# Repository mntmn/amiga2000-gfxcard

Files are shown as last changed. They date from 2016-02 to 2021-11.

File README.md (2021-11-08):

# MNT VA2000, an Amiga 2000 Graphics Card (Zorro II/III)

_Update January 16th, 2017:_ The MNT VA2000 is now a finished product (credits go to Scarab Hardware for making this happen) that you can buy. I shipped the first batch of 100 cards on christmas 2016 and the second batch is now being made. 

You can still grab one: http://mntshop.bigcartel.com/product/mnt-va2000-amiga-graphics-card-zorro-ii-iii-batch-2-preorder

The latest firmware update and drivers are always available here: http://mntmn.com/va2000/

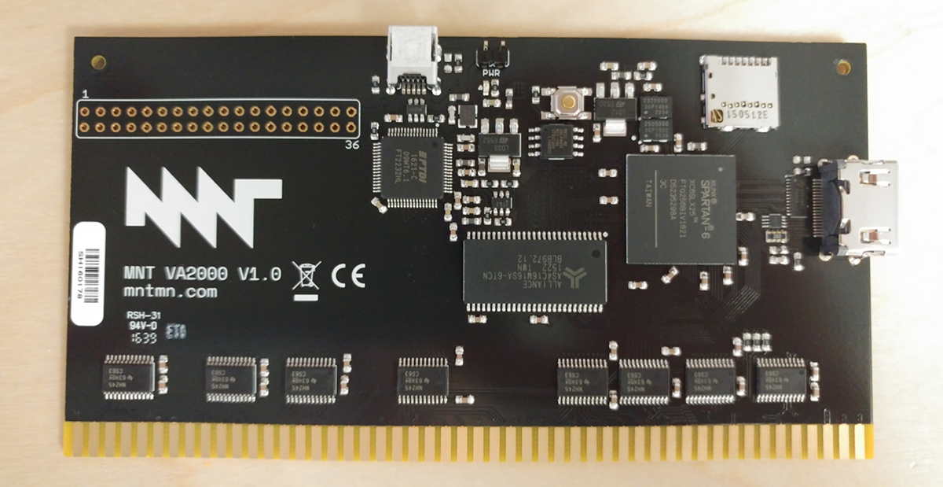
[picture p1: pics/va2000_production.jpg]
MNT VA2000 Finished Product


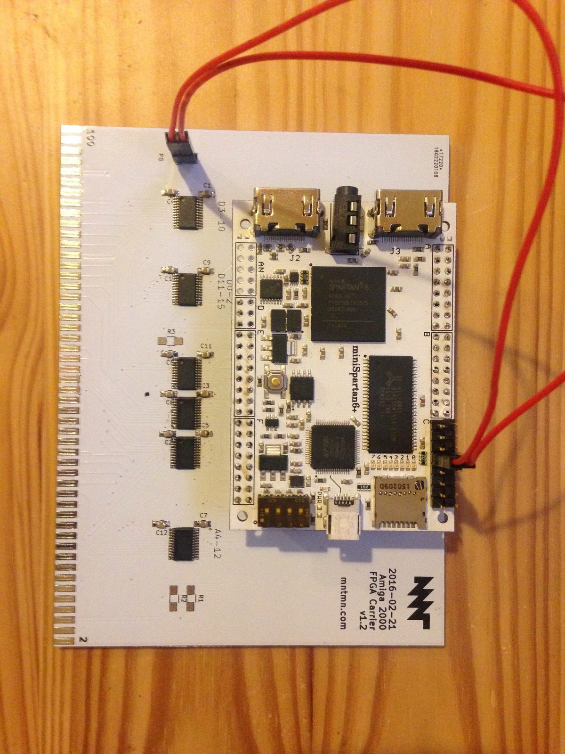
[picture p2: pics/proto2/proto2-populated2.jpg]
MNT VA2000 Protoype 2 Populated


This repository contains my Kicad schematics and Xilinx ISE/Verilog files for my graphics card project. This is a work in progress, started in October 2015. The first 4 prototypes were assembled in Jan/Feb 2016 and had noise problems, so I started a redesign on Feb 13, 2016.

On Mar 27th, 2016, the redesign worked and I could load a 16 bit 565BGR coded raw image from floppy into the graphics card that displayed a 1280x720p resolution (75mhz pixelclock).

In April 2016, I managed to get Workbench running via a reverse engineered Picasso96 driver.

The working Xilinx project for the new target platform (Scarab miniSpartan 6+) is now in the z2-minispartan folder. The main source file is: https://github.com/mntmn/amiga2000-gfxcard/blob/master/z2-minispartan/z2.v

Contains a modified SDRAM controller (Verilog) and a DVI encoder (VHDL) by Mike Field. See credits and license at the end.

# How I decided to make a graphics card for my Amiga 2000

_TL;DR: I spent my free time over the course of 5 months to make two open source graphics card prototypes for the Amiga 2000. I will make a third, release version; details at the end._

Somewhere in the middle of 2015 I revived my old A500 and acquired again an A1200. Using the A1200, I learned C++ and the basics of web programming in the late 90s. I also used to play many fantastic Amiga games back in the day, made my first music in ProTracker and my first digital graphics in Deluxe Paint. Re-experiencing the old system that was once so ahead of its time again made me curious about Commodore's history – and especially about the later, big and ambitious Amiga models (A3000, A4000…). This coincided with Amiga's 30th anniversary. A lot of new interviews with the original team(s) popped up, including Dave Haynie, who was a main designer of the A2000 and the Zorro III Bus.

I checked eBay for the "big" Amigas I never had, expecting them to be cheap, but found out that these boxes had turned into valuable collector's items. At the same time, A2000s were (and still are) affordable, so I chose to get one and put a 68040 and a SCSI card in it. But the system couldn't realize it's full potential; in the 90s you could already get, for example, a "Picasso" graphics card that could do VGA (and higher) resolutions at 16 or 24bit color depth. Nowadays, these totally outdated cards are rare and sold for ridiculous prices. My A2000 was stuck with 640x256 PAL resolution, 64 colors (ignoring HAM) or headache-inducing interlaced modes. 

Because of my work with microcontrollers, writing an OS for Raspberry Pi (http://interim.mntmn.com/) and my interest in low-level computer architectures in general, I decided in October 2015 in a feat of madness: "I'll just make my own graphics card. How hard can it be?"

It turned out to be a very, very challenging project, but luckily I got much further than expected. On the way, I had to learn how to design a PCB and get it manufactured, how to work with SMD parts, how to program in Verilog and synthesize code for an FPGA, how SDRAM and DVI/HDMI work (or how to get them to do at least something). I also had to find out how to write a driver for the sadly closed/undocumented Picasso96 "retargetable" graphics stack for AmigaOS 3.

The Amiga is probably the last 32-bit personal computer that is fully understood, documented and hackable. Both its hardware and software contain many gems of engineering and design. I hope that one day, we can have a simple but powerful modern computer that is at the same time as hackable and friendly as the Amiga was.

## The "engine": FPGA and SDRAM

As a platform for my first attempt (ultimately a failure) I chose the Papilio Pro development board, which has a Xilinx Spartan 6 FPGA and a few megabytes of SDRAM connected to it. It also has two pin headers that break out some of the general purpose input/output pins of the Spartan. I thought, OK – I could use the RAM to store the image (a framebuffer), and run a loop that goes through all the columns and rows of the picture in the correct speed and just output the bytes from the RAM to R,G and B output lines. I did this before with little Atmel microcontrollers – "bit-banging" a VGA image directly from the CPU – so I knew it was possible. I just didn't know that SDRAM (synchronous dynamic RAM) was a lot more complex to use than the integrated SRAM (static RAM) of common microcontrollers. To access data in a dynamic ram, you have to open banks, rows, precharge, refresh, and take care of startup and access delays:

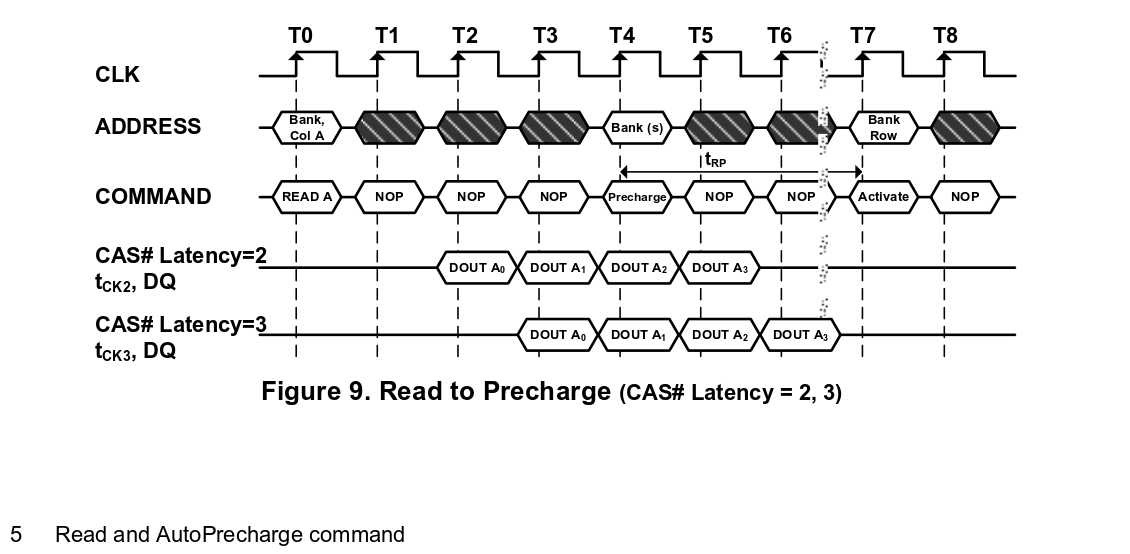
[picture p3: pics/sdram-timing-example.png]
SDRAM Timing Example from Alliance Memory Datasheet


Source: http://www.alliancememory.com/pdf/dram/256m-as4c16m16s.pdf

Mike Field's open source SDRAM controller written in VHDL and Verilog helped me get the RAM working. I connected an Arduino to the Papilio and used it to send a few address bits and an "on/off" bit to toggle pixels in the framebuffer black or white. This contraption was able to draw basic fonts on my VGA display, and they were successfully kept in the SDRAM. 

The next step was connecting the FPGA+display part to the Amiga 2000.

## Zorro II: Reads and Writes

The original Amiga Hardware Manuals helped me understand the Zorro II bus. It is basically an extension (arbitrated by a bus controller chip) of the pins of the Motorola 68000 CPU. The 68k is extensively studied and documented. I understood that I needed a mechanism that would allow the 68k CPU to write data (pixels) to the graphics card's RAM and another for reading back parts of the screen (for scrolling and moving around things).

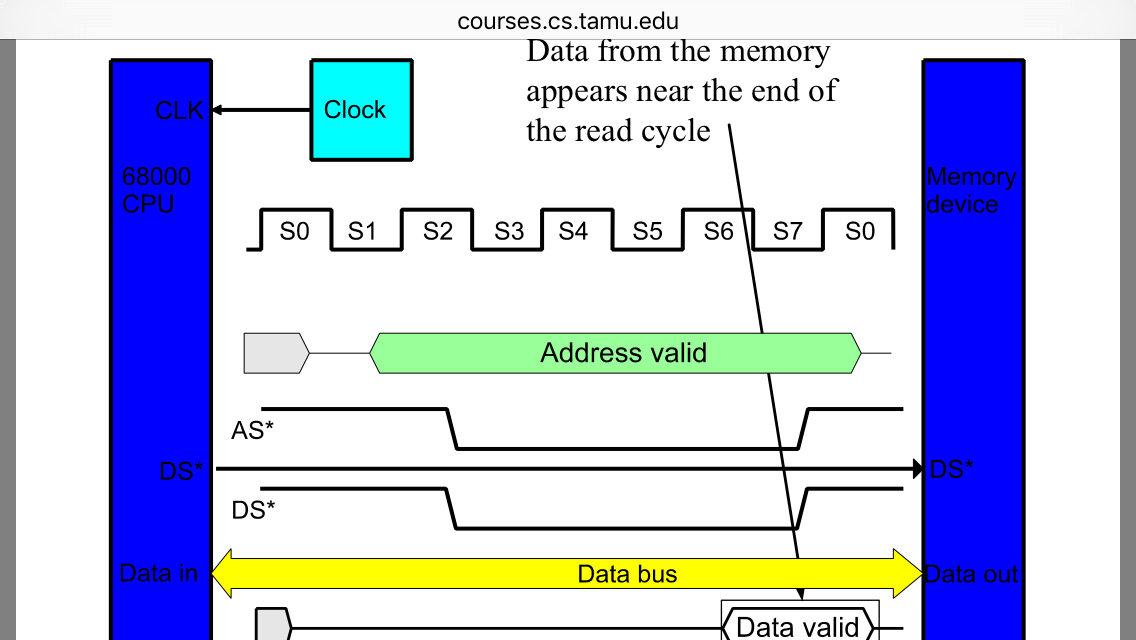
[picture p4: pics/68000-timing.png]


So I fired up the open source circuit design tool KiCad and started some schematics. The first task was to define the Zorro port as a component with a whopping 100 pins. Of course I made a lot of little mistakes at first and I had no idea why one would need so many different signals. It turned out that I only needed a subset of the pins to get my job done:

1. Address Bus (A1-A23)
2. Data Bus (D0-D15)
3. Upper and Lower "Data Strobes" (UDS / LDS)
4. READ, /AS, DOE, signals which the Amiga uses to communicate if it wants to read or write, if it presents a valid address and if it expects a device to send data.
5. Power (5V, GND)
6. Autoconf (/CFGIN, /CFGOUT)

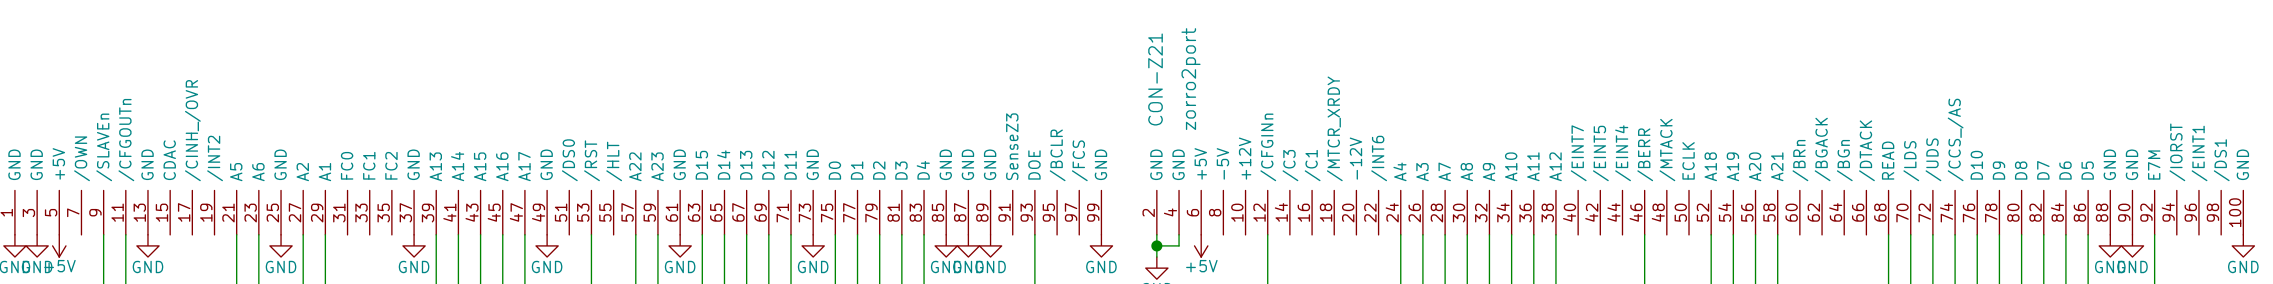
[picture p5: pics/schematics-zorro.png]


Source: http://courses.cs.tamu.edu/cpsc462/walker/Slides/68K_Timing_Diagrams.pdf

I figured that I needed to connect most of these signals to the FPGA and then write another loop in Verilog that would interpret the Amiga's bus commands and act on them (store the data given on the bus in the RAM or return stuff from the RAM). 

On the other side of the FPGA, I decided to place an Analog Devices ADV7125 digital to analog converter (DAC) chip that would generate the analog R, G and B channels for the VGA port from the bits coming from the framebuffer.

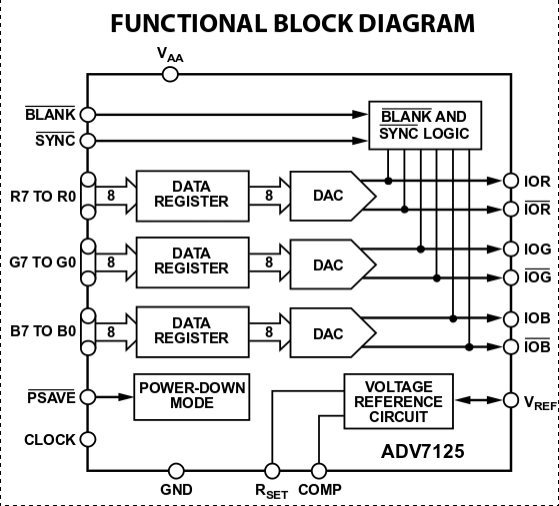
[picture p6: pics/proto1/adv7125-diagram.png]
Analog Devices ADV7125


Source: http://www.analog.com/media/en/technical-documentation/data-sheets/ADV7125.pdf

The next hurdle appeared: The Spartan communicate with modern 3.3V logic levels, but the Amiga used legacy 5V signals. So I needed to put voltage translators (also called level shifters) between the Zorro and the FPGA pins. I decided to split the signals into bundles of 8 and use six 8-bit "auto-direction-sensing" TXS0108 chips.

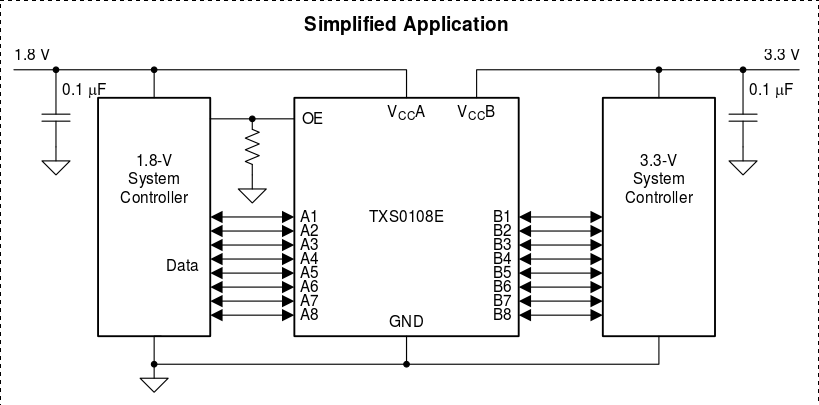
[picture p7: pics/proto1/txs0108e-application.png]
Texas Instruments TXS0108


Source: http://www.ti.com/lit/ds/symlink/txs0108e.pdf

## Mistake: Trying to be too smart

I then realized that the Papilio, the FPGA board I had, didn't have enough I/O pins to connect to the 48 Zorro signals and the 16+2 pins required for the VGA DAC output. Actually, it had a lot less pins. So I made a huge mistake and decided to use two 16-bit port switching chips and "select" on the fly a "window" of the Zorro pins that would be relevant at each state of my bus communication loop; I thought I didn't need to access the data pins at the same time as the address pins. And because the FPGA runs at a much higher frequency than the Zorro bus, I could first read one part of the address, switch one of the switches via a control pin and then quickly read the other part to get the whole address.

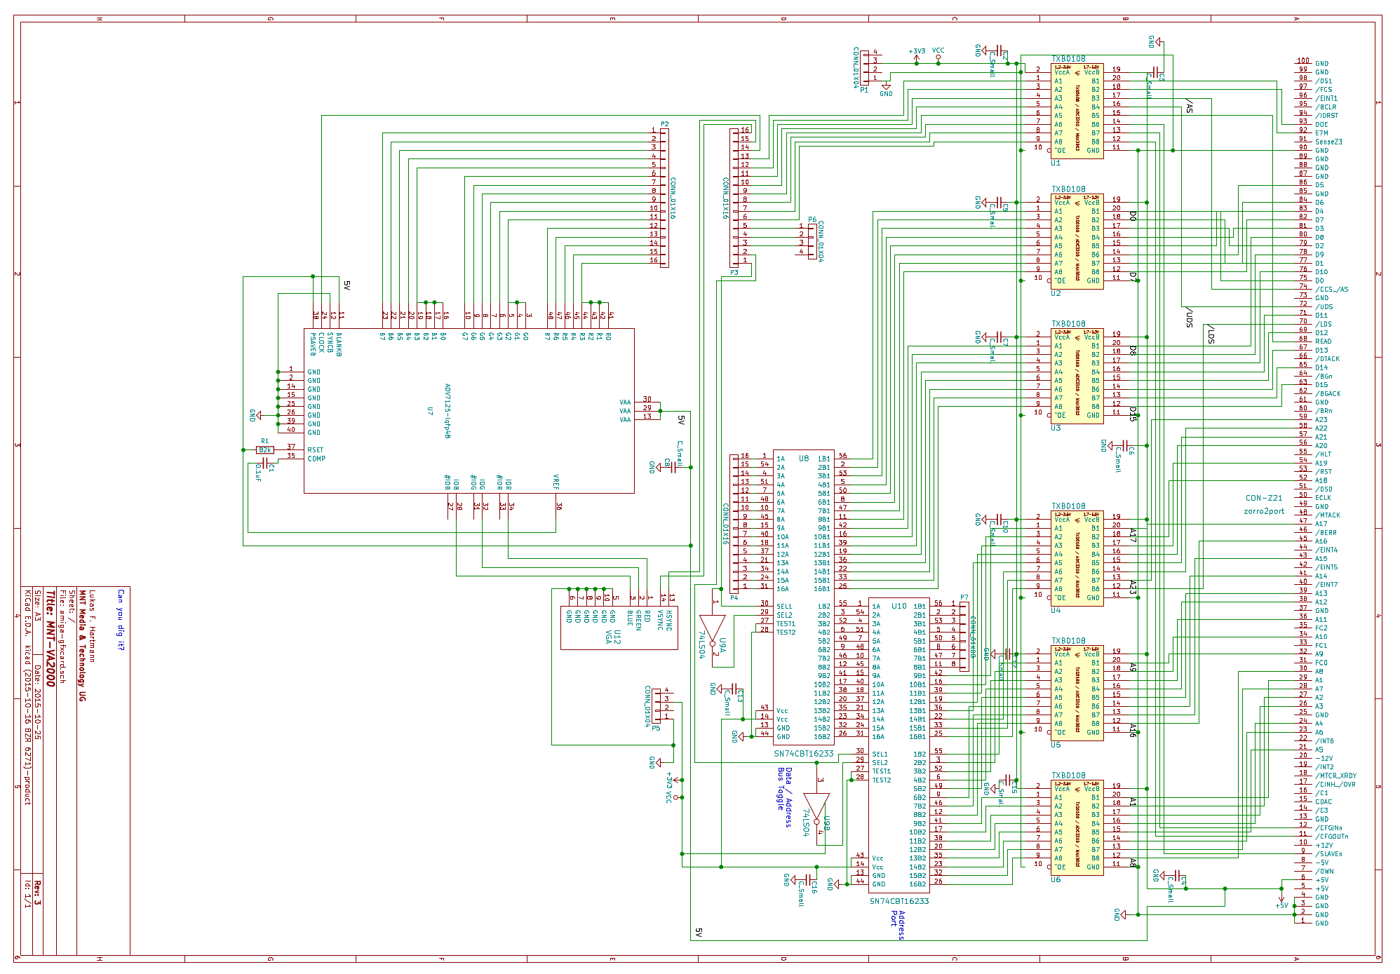
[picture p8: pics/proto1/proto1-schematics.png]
Failed Prototype 1 Schematics
 

After drawing up a few versions of the schematics and collecting the fitting footprints for the components from various GitHub repositories, I imported them into KiCad's PCB design tool and started drawing the actual circuit board. I had no experience doing this, so I worked through tutorials or just looked at how other people were solving their board design problems. Finally, I uploaded the exported "Gerber" files to DirtyPCBs.com, ordered, waited 8 weeks and nothing happened. I made the mistake of choosing the AirMail option, which has no tracking, and the package was lost. After getting no support from DirtyPCB, I chose to try again, this time selecting the DHL option with tracking and finally got my first ever printed circuit boards in the mail around 10 days later! By now, it was the middle of January 2016.

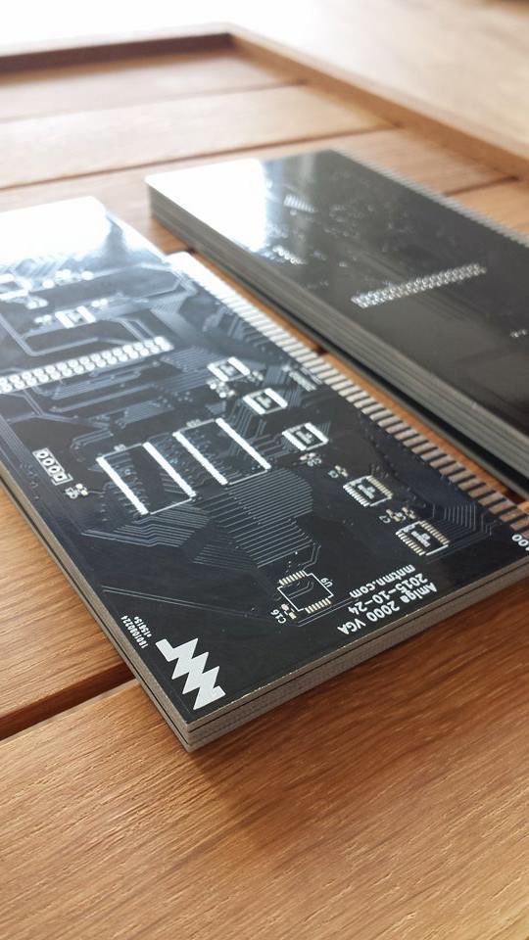
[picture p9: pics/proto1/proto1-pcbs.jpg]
Prototype 1 PCBs


In parallel, I ordered the required chips and parts from Mouser; luckily I had gotten most of the footprints right, except for one logic gate IC that turned out to be a mistake anyway. I got to work and tried to solder my first SMD ICs using my trusted ERSA iron. 

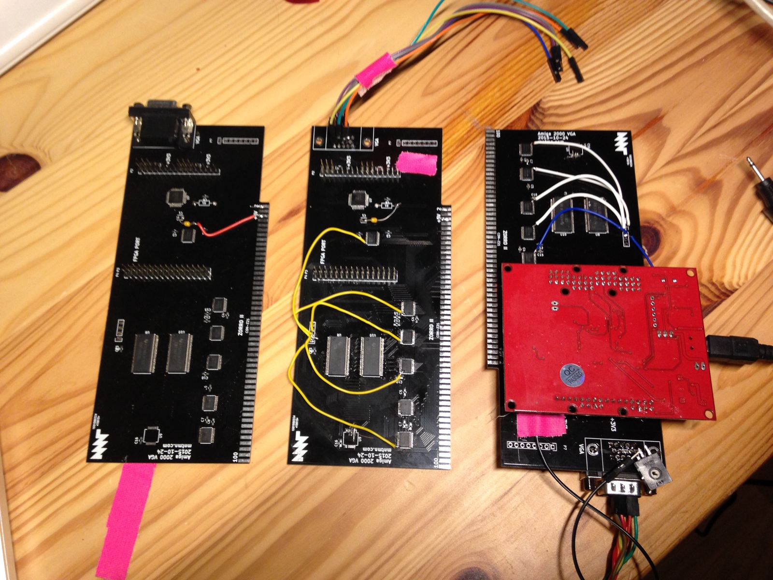
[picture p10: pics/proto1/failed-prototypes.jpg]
Failed Prototype 1 Board
 

It turned out I had made a number of critical mistakes in designing the boards: all of the voltage translators' OE pins were tied to GND when they should have had 3.3V, so they required manual bending and patching of the OE leg (yellow cables in the picture). I accidentally switched 3.3V and GND pins on the FPGA carrier headers, so I needed to reroute them with wires on the back. Because I misinterpreted the Multiplexer IC's datasheet, I also planned for a negating logic IC on their SEL pins which was totaly wrong. In the end I had to solder bridges instead of placing the 74LS04. 

After fighting through all of these issues and burning through a few boards, I finally got some results. As a first debugging step, I wrote a poor man's logic analyzer in Verilog that would record 640 cycles of all the Zorro Bus signals to FPGA registers (BRAM) and dump them as colorful lines on the VGA screen. This turned out to be a helpful instrument. I wrote a very simple program in 68k assembler for the Amiga that would read – in an endless loop – a word from address $e80000 and write it to $dff180 (a background color register). I made a boot floppy that would run the program, put my card in the A2000, flashed the code and turned everything on.

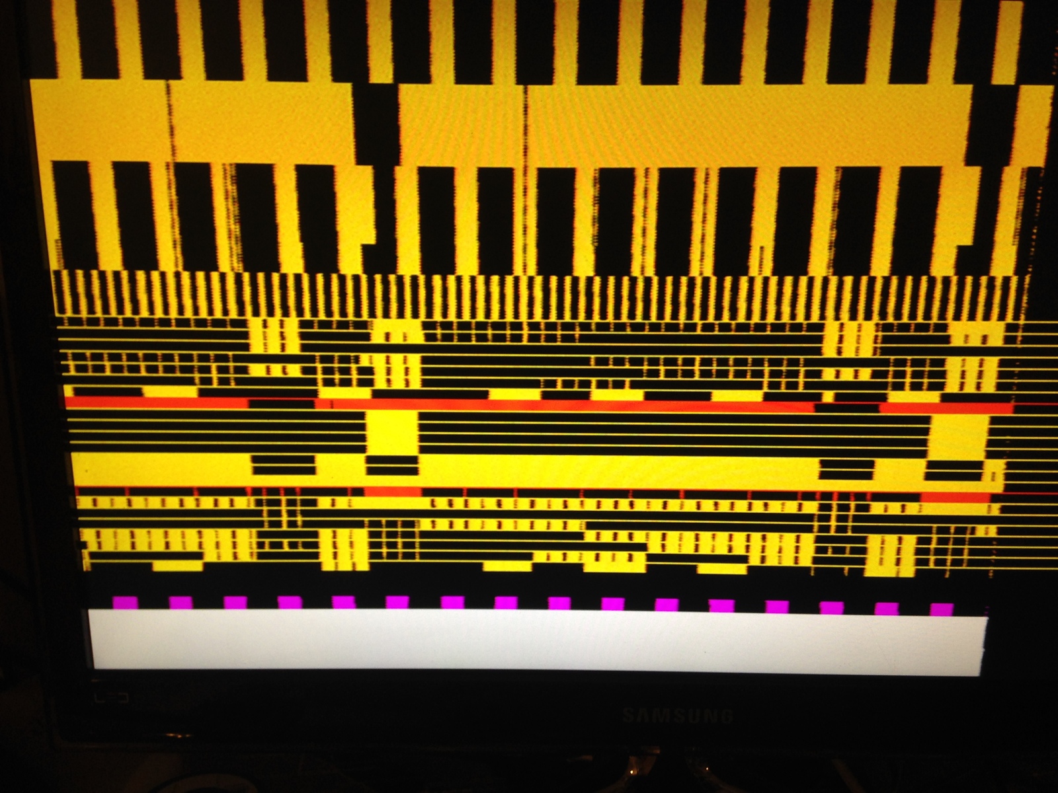
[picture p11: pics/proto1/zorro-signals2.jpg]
Prototype 1 Zorro Bus Analyzer 1
 

The first 5 longer, stretched rows in this picture are the signals DOE, READ, /UDS, /AS and E7M (Amiga 7Mhz Clock) sampled at 100 Mhz/Column, so the whole picture displays a time sample of 6400ns (nanoseconds) or 6.4&mu;s (microseconds).

The following lines on the grid represent the Address bits A23-A1 in descending order. A0 does not exist; the 68000 selects an upper, lower or both bytes (word access) using /UDS and /LDS instead.

The address signals have regular little chops in them; this is a nasty side effect of switching the multiplexers. You can also see that address bit A9 is constantly turned on, probably due to a soldering error. At least it's possible to see the 68000's read and subsequent write accesses (the only hole in the READ row, second from the top). Ignoring the broken pins A9 and A17, the READ occurs as expected on address binary 111010000000000000000000 and the WRITE on 0b110111111111000110000000. Due to the constant noise and other random failures, I couldn't reliably get the Amiga to read from my card, but it worked at least sometimes, giving me hope.

After a few nights of trying to fix this very unstable system, I gave up and went back to the drawing board.

## Redesign and Breakthrough

My new strategy was:
1. Make the board much simpler, focus on voltage translation and find a FPGA board with enough IOs
2. Get a decent (de-)soldering station and learn a better SMD soldering technique

I shopped around the web for FPGA boards that combine SDRAM with lots of IO breakouts and found Scarab Hardware's miniSpartan6+, which has a nice small formfactor and includes two HDMI ports, a mini SD card reader and even an audio jack. 

I redrew the schematics to include no more switches, different level shifters with explicit direction inputs (NXP 74LVC8T245), plenty of bypass capacitors and dropped the analog VGA circuit. 

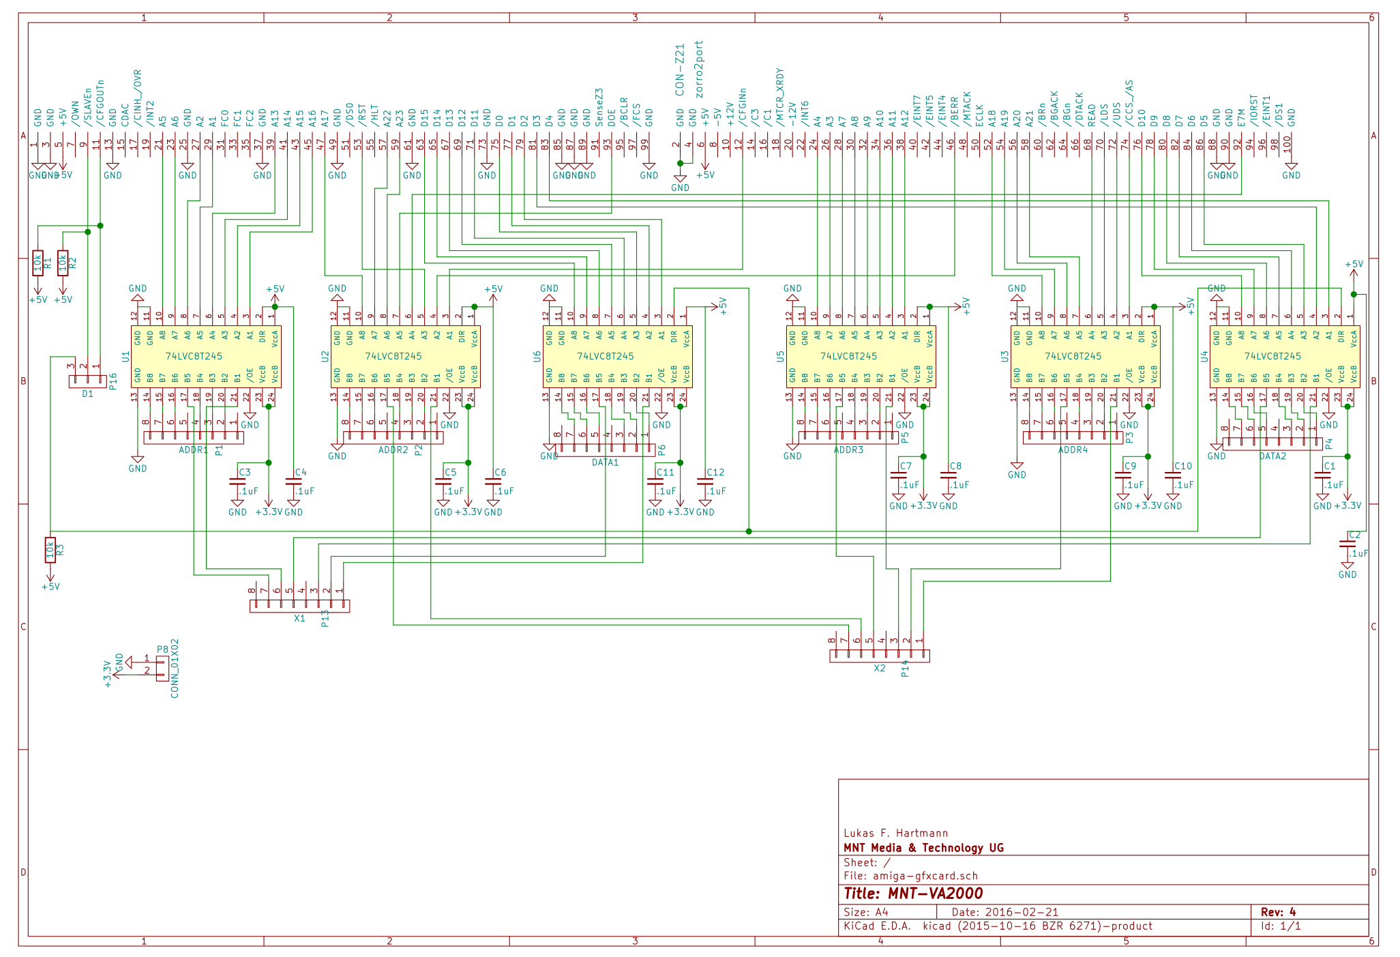
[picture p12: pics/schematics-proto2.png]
Prototype 2 Schematics

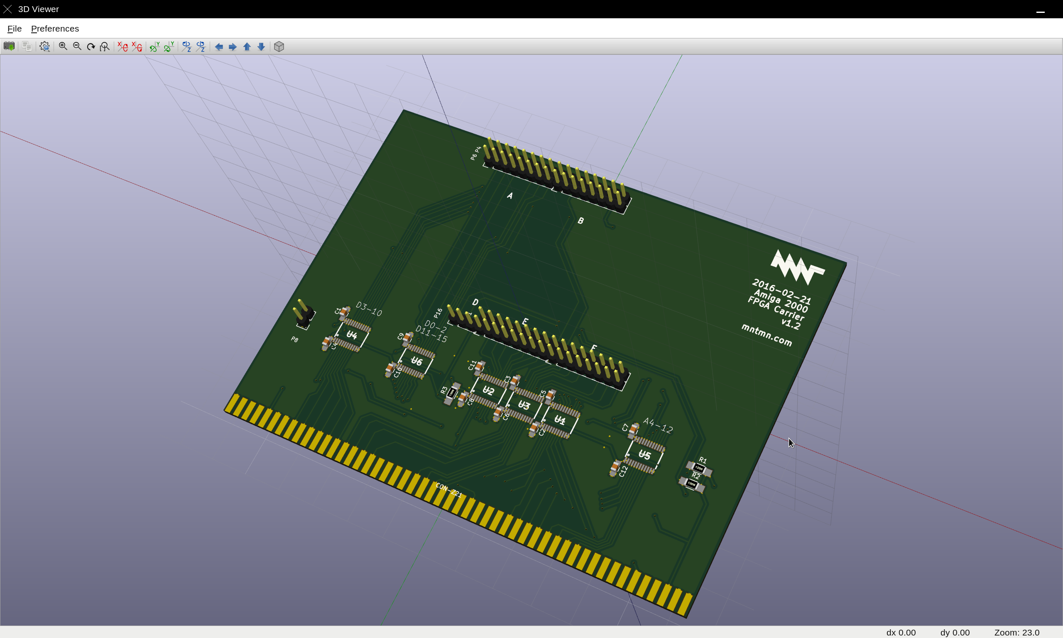
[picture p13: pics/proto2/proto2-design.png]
Prototype 2 Design


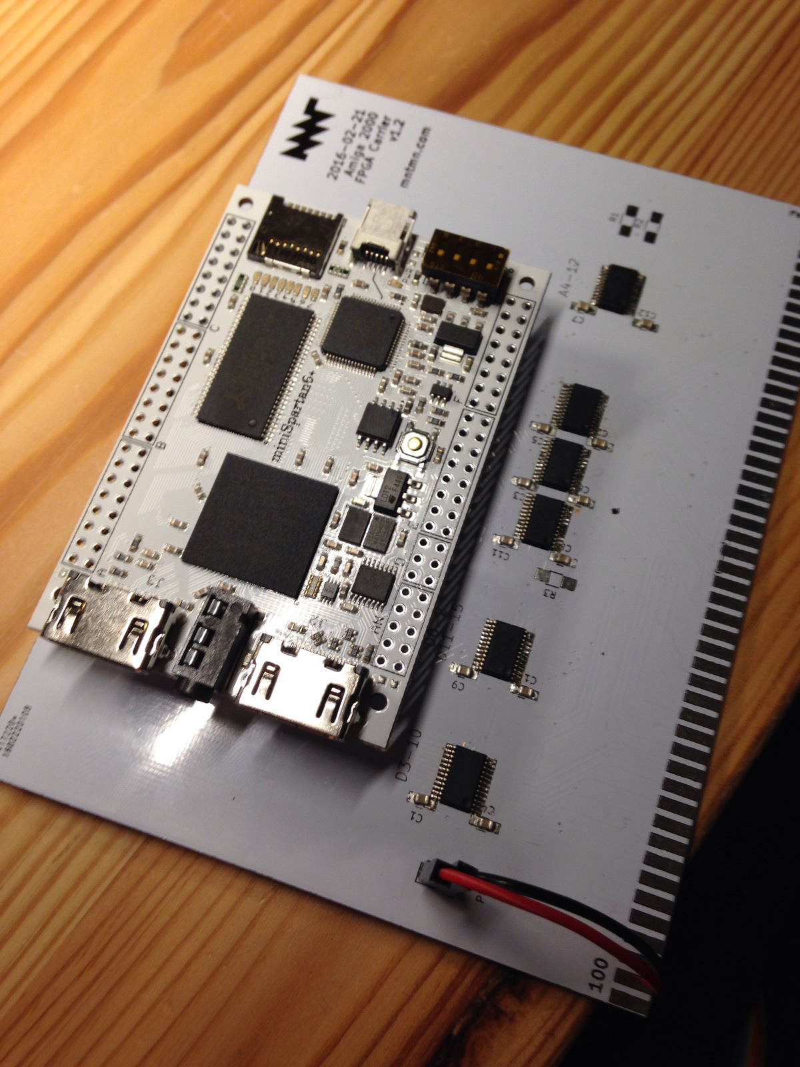
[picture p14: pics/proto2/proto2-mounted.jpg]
Prototype 2 with miniSpartan mounted


To solve point 2, I ordered a Yihua 853D rework station on Aliexpress and experimented with hot air solder paste soldering (not a success for me, the results were quite messy). I then watched Sparky's super helpful SMD soldering techniques again: https://www.youtube.com/watch?v=z7Tu8NXu5UA

To my surprise, using the "dragging" technique with plenty of flux and a chisel tip (Sparky recommends a "gullwing" tip) at around 270 Celsius yielded the cleanest results I had so far.

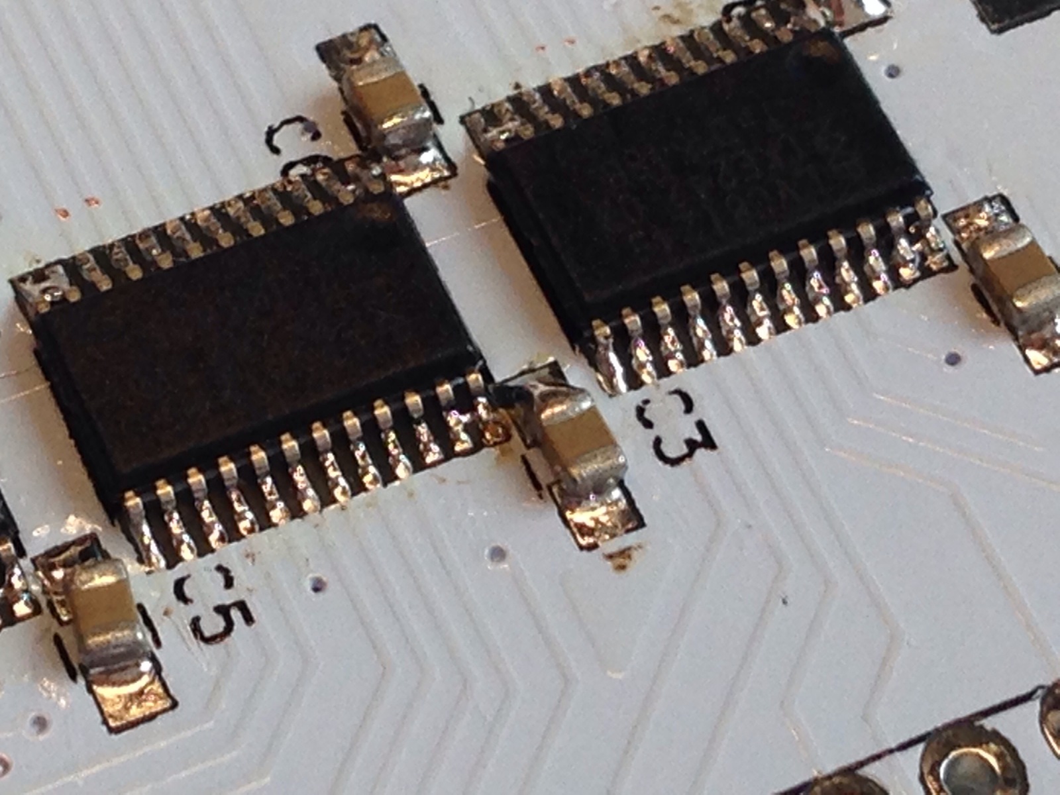
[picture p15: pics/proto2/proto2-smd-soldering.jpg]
Drag Soldered Voltage Translators

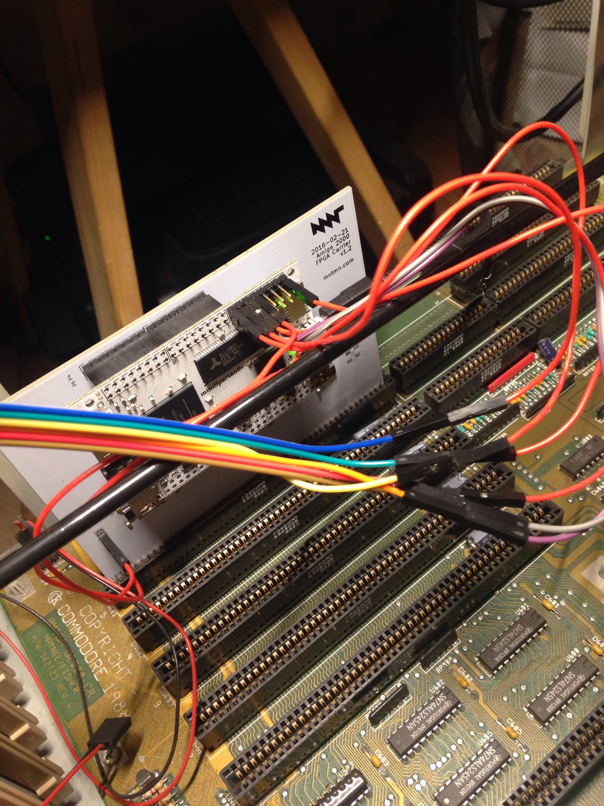
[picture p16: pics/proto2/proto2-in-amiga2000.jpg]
Prototype 2 inserted into Amiga 2000


Version 2 rewarded me with super clean signals. I used 5 digital outputs of the FPGA and connected them to a VGA monitor for testing, and I could reliably "lock" my Verilog state machine to the Zorro READ cycles. 

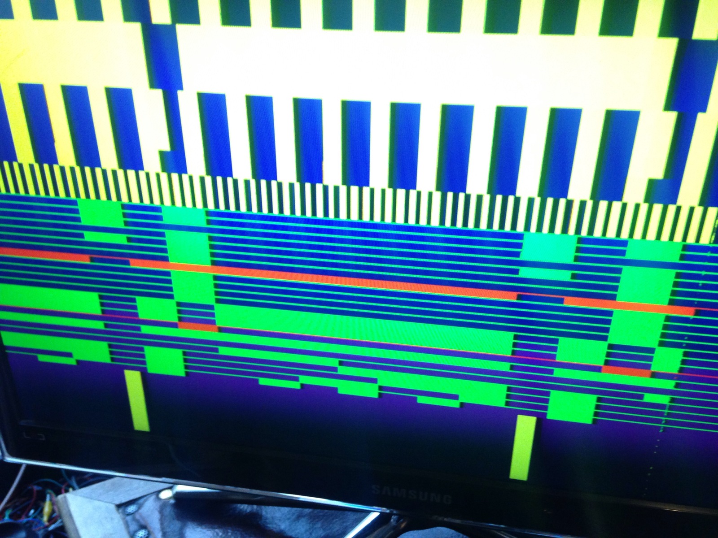
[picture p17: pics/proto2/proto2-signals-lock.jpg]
Prototype 2 Clean Signals


I proceeded to write a little 68k assembler program that reads the Amiga's mouse X and Y registers and translates them into an address for the graphics card to write a pixel to. And voila, I had a primitive painting program:

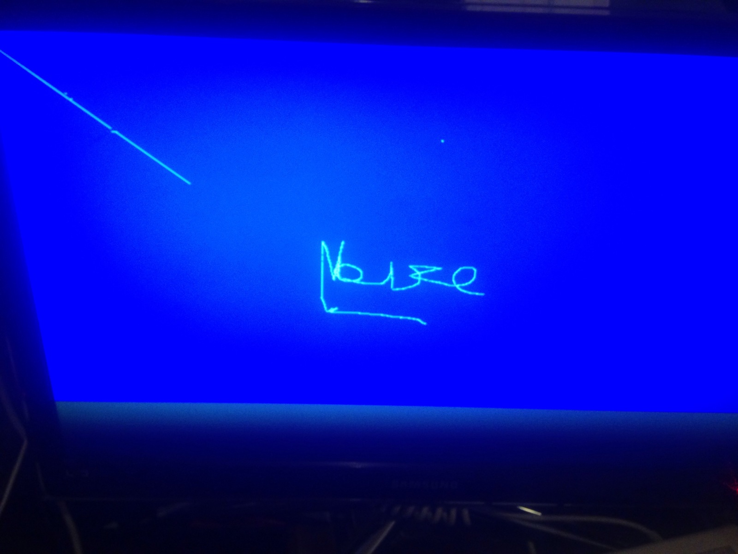
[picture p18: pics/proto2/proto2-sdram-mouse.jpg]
Prototype 2 Assembler Mouse Test


The main problems I had to solve now revolved around tweaking the state machine so that it would arbitrate the single RAM port between fetching pixels for display on the screen – something that is almost constantly happening, only not during blanking periods – and Amiga reads and writes to and from the graphics RAM. I still haven't completely solved this challenge, but I've come far enough for the system to be somewhat usable. The current algorithm works like this:

### Fetching

Shortly before the beginning of each displayed row, start the pixel _fetching_ process. In this state, a line buffer is normally filled with pixels for that line from SDRAM as fast as possible (133 MHz clock).

### Displaying

The VGA/DVI output process reads the pixels to be displayed from this line buffer at the pixel clock frequency (60~75 MHz for a 1280x720 output). This means that the fetching process always needs to be at least as quick or quicker than the displaying process, or there will be glitches (doubling of the last line).

### Host Writes

When the host CPU wants to write to graphics RAM, we don't let it write directly to the SDRAM (because we're probably currently accessing it for fetches). Instead, we save the host's write address and data to a _write queue_. The queue is drained (processed) whenever the line fetching is done for a row and in blanking periods.

I tested the stability of writes by putting the "mon" tool (http://aminet.net/package/dev/moni/mon165) on a floppy together with a raw 16 bit image (rgb565) of a mountain. I loaded this directly into graphics card memory starting at $600000, displaying the first picture ever on my board:

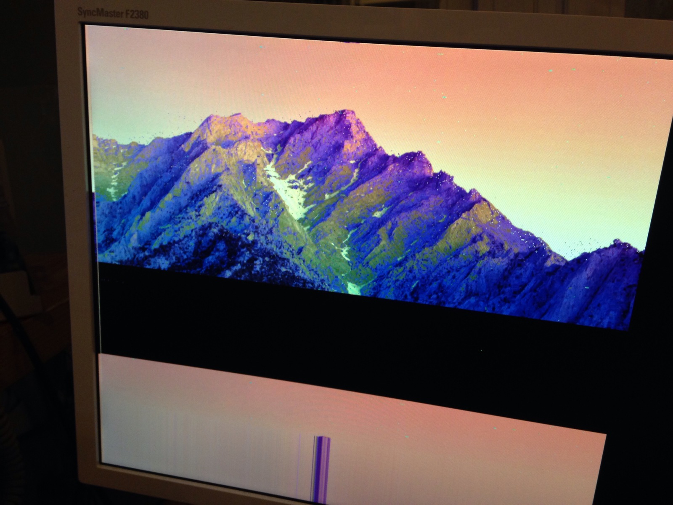
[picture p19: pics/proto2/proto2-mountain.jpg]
Prototype 2 Picture Load Test


### Host Reads

I found host read timing to be significantly harder to get right, and it's still not perfect. Host reads can't be put in a queue and have to be processed immediately. This interrupts the fetching process; if the host needs to read from a totally different memory location then the display engine is fetching, the SDRAM has to close, refresh and reopen rows, which is a time consuming process. So far, reads from the host cause temporary distortions (glitches) in the display output. I plan to mitigate these problems using either burst mode reads and fast switching and/or inserting CPU wait states via the XRDY signal.

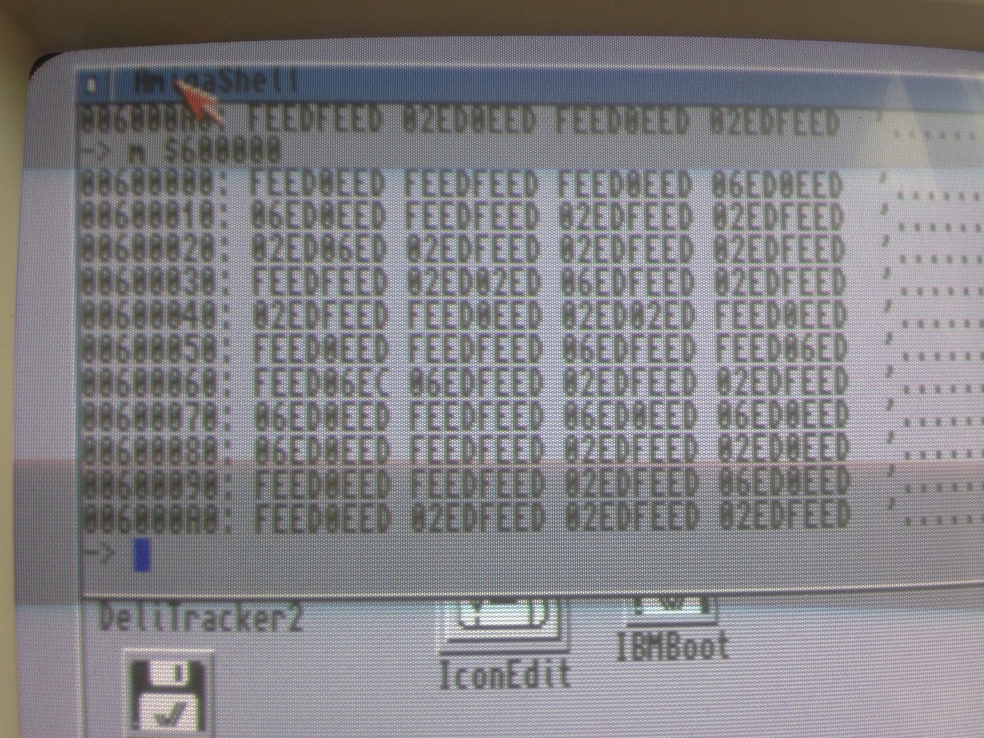
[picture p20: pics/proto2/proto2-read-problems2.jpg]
Prototype 2 READ Problems

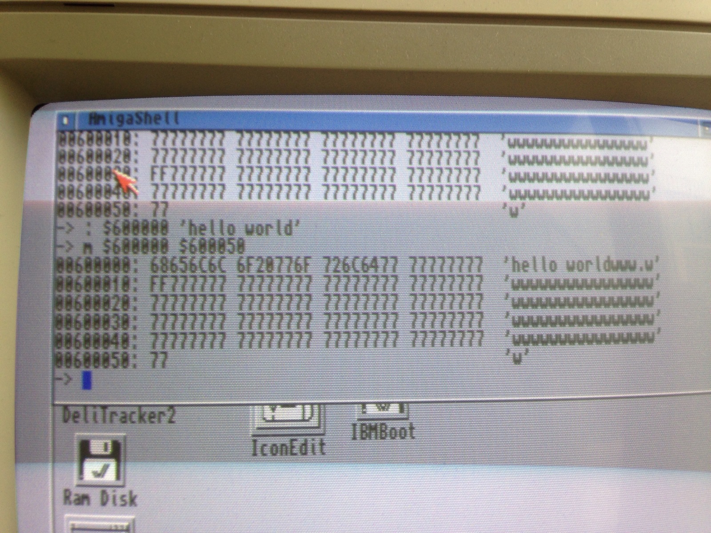
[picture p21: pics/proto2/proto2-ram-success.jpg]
Prototype 2 better READs


## Picasso96: Writing a Driver for a Closed System

Picasso96 was one of two competing systems (the other being CyberGraphX) integrating graphics cards into the Amiga "Monitor" Device system. P96 also ships an "emulation.library" that patches all system windowing and drawing functions and redirect the legacy bit-planar based output to the new "chunky" pixel formats. After the death of Commodore and the Amiga market, Village Tronic, the authors of P96, disappeared. It's unclear where the sources and internal documentation ended up, and the original developers didn't respond to my emails about it.

I looked at the publically available P96 binaries and documentation and figured that I would need to write a _.card_ file, which is basically a normal Amiga library executable with a different file name extension. From inspecting the binaries and the UAE Picasso96 module, I figured out that my library would have to export a number of function symbols:

- FindCard() to detect if the board is available. I cheated and returned -1 (card found) in d0.
- InitCard(), the most important function, has the job of initializing the board and to fill in a "BoardInfo" structure with details like available pixel color formats, board type, horizontal and vertical maximum resolutions and timings (See: https://github.com/tonioni/WinUAE/blob/master/picasso96.cpp#L1082). This function also stores the addresses of the following callback functions into the BoardInfo structure.

- CalculateBytesPerRow() – Has to return the offset in bytes from one row of pixels to the next. For example: 2048 for a 1024 pixel wide 16-bit display.
- CalculateMemory() – Should remap an address in a1 to another (internal?) address. I just return a1 in d0.
- SetColorArray() – Set the palette for 256 color indexed CLUT mode. I didn't implement this yet.
- ResolvePixelClock() – Supposed to return an index into an array of pixel clocks. Return 0.
- GetPixelClock() – Given an index, return a pixel clock. I just return a fixed number of 60000000.
- SetPanning() – Called when a new P96 screen is opened. In the UAE code, they use it for screen clearing.
- SetSpriteColor() – Just return 0.
- SetDisplay() – enable/disable the display. Just return 0.
- WaitVerticalSync() – Just return 1 or actually sync to the screen refresh process.

Unknown functions: (Stubs that can return 1/0)
- SetSwitch() – Something related to switching between native Amiga and Picasso96 screens.
- SetDAC()
- SetClock()
- GetCompatibleFormats()
- GetVSyncState()
- SetMemoryMode()
- SetWriteMask()
- SetReadPlane()
- SetClearMask()

There is also a number of entrypoints to allow hardware blitting (block copying), rectangle fills and line drawing. I don't implement these yet, but they should speed up working with the card significantly. 

To activate my driver, I had to change the Picasso96 monitor file's "BoardType" tooltype to "VA2000". And indeed, it loaded my VA2000.card without complaining. I then launched the Picasso96Mode application that allows (somewhat erratically) to edit and enable/disable screen modes. To get it to do anything, I copied by trial and error the supplied Picasso96Settings.64 to DEVS:Picasso96Settings and attached the settings to my board that was now showing up in Picasso96Mode's "Board" menu. To my surprise, I could activate the 800x600 mode in "HiColor" and was greeted with a test image and then a somewhat distorted Workbench Screen:

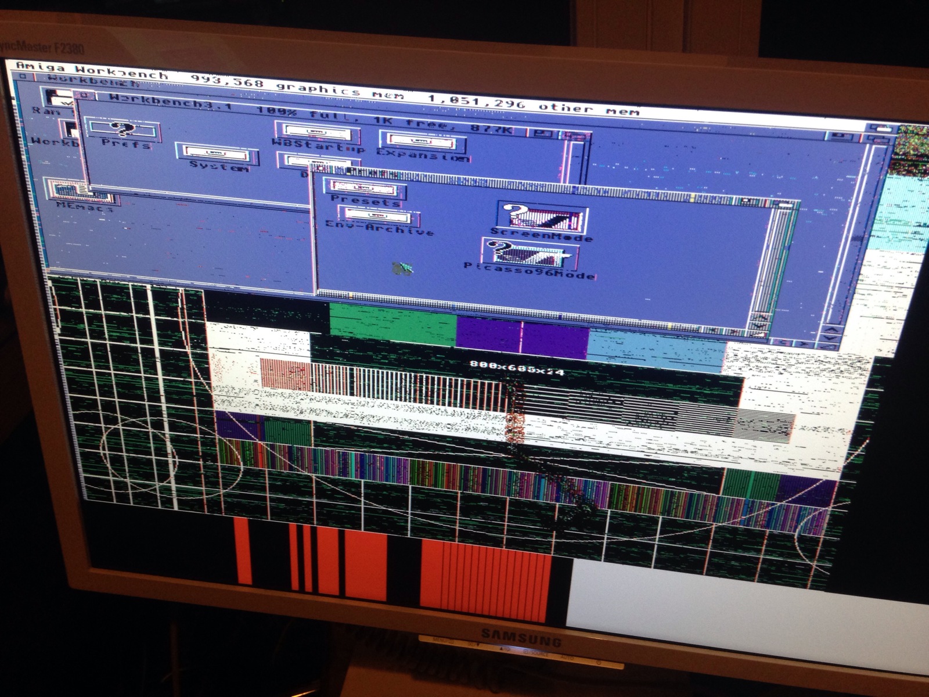
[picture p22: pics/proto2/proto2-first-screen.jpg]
Prototype 2 first Amiga Workbench Screen

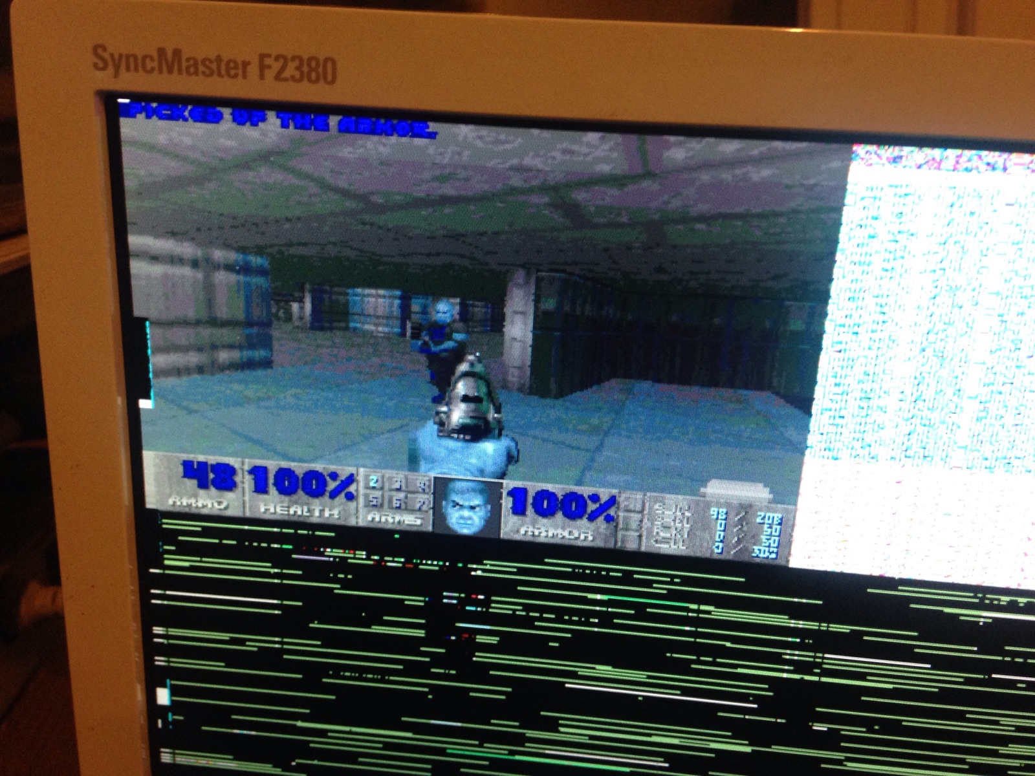
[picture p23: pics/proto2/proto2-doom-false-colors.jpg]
Prototype 2 first Amiga Doom Screen


Sprites such as the mouse pointer are emulated in software by Picasso96. In this image you can see some red noisy "turds" from where the mouse pointer was in the frames before – this shows that reading from card memory wasn't working right:

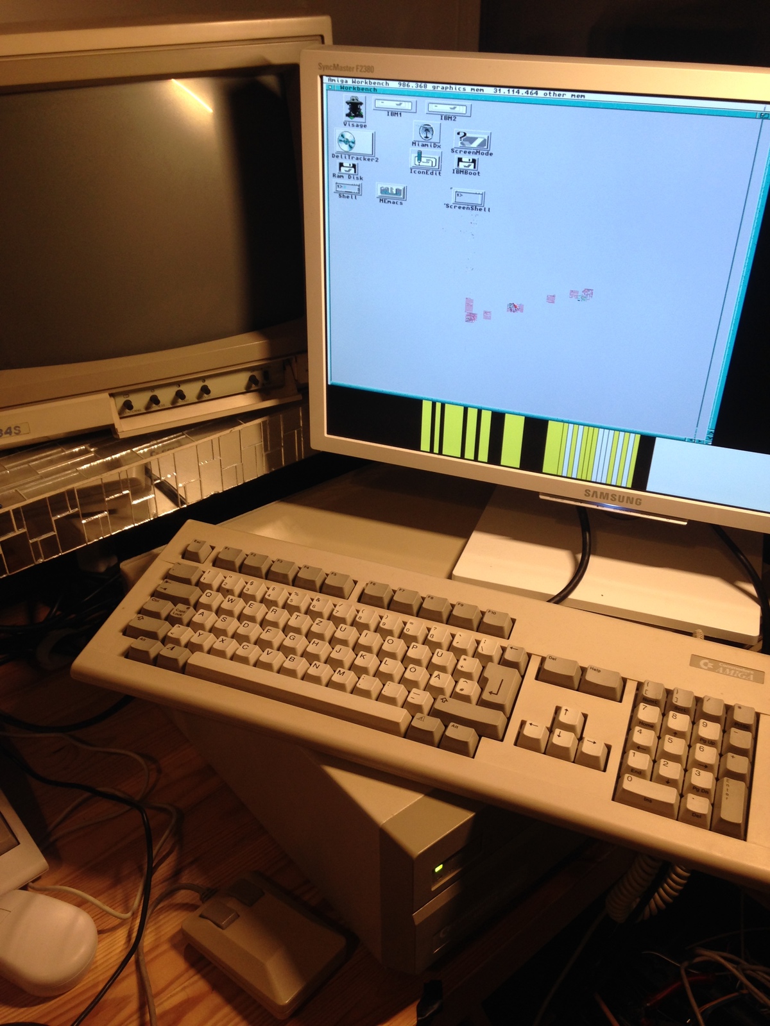
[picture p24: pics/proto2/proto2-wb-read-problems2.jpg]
Prototype 2 Workbench READ noise


## Fixing the Colors

After playing around with Workbench and several applications, I noticed that somehow I could get only around 64 colors out of the 65535 that should be displayed. This turned out to be a problem of the color format. Picasso96 supports a bunch of 16 bit color modes; for some reasons I had used a "PC" mode (gggrrrrrbbbbbggg) which results in a weird truncation of the color space.

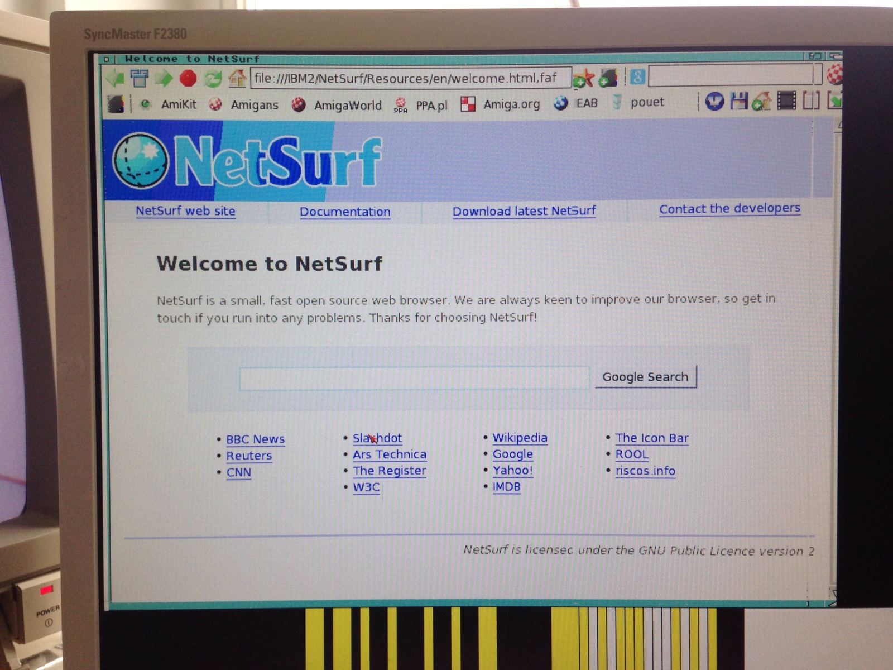
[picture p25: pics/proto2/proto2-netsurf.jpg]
Prototype 2 Amiga NetSurf

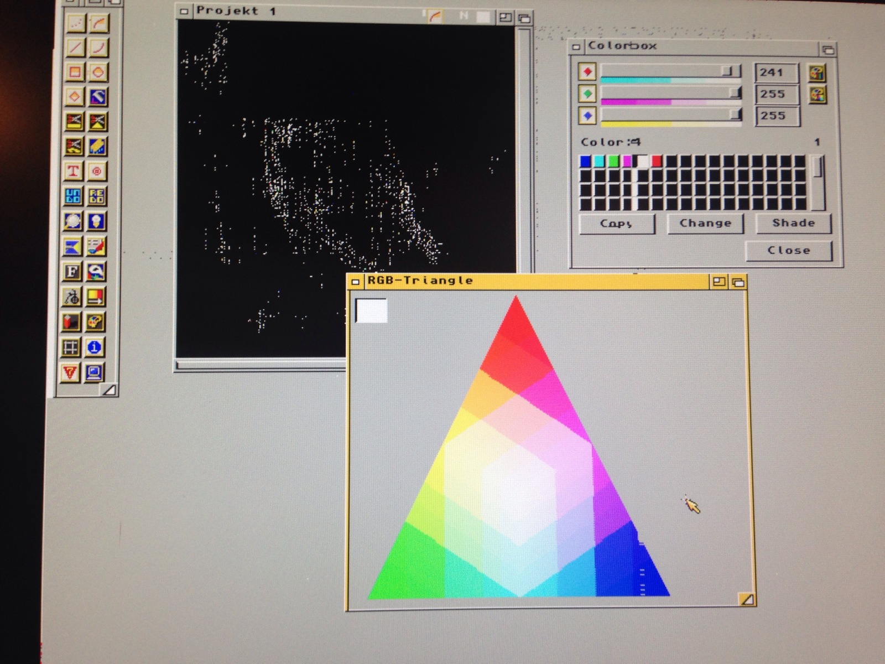
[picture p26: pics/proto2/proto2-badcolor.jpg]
Prototype 2 Amiga HiColor Problems


By changing the list of supported color modes in my driver to a non-PC-mode (RGB565), I was able to fix the problem and enjoy "High Color" in 800x600 on my Amiga 2000:

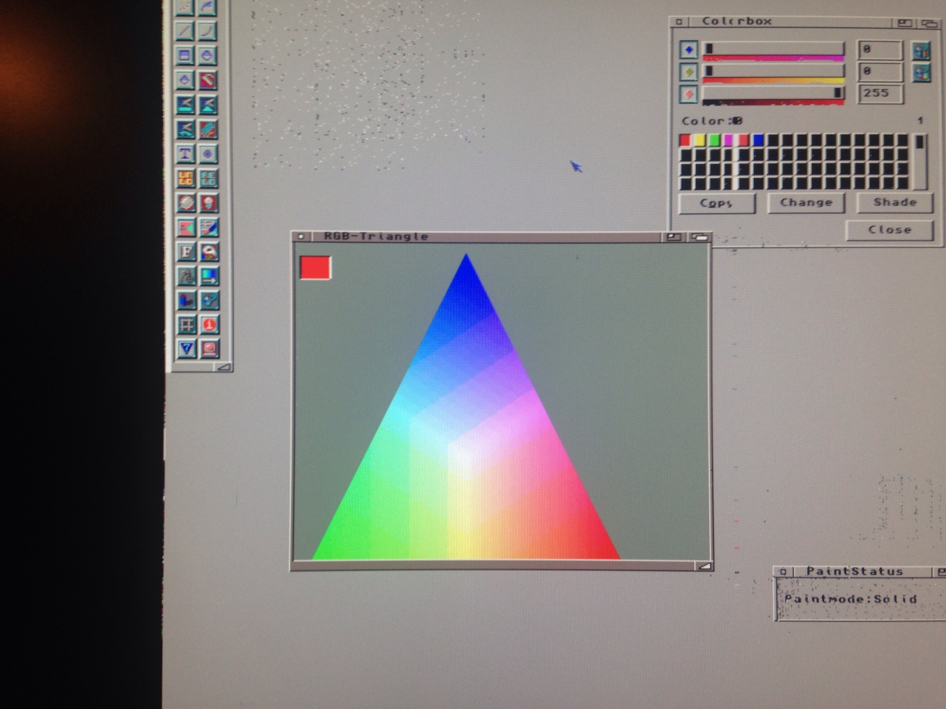
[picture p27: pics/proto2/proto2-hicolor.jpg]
Prototype 2 Amiga HiColor Triangle XiPaint

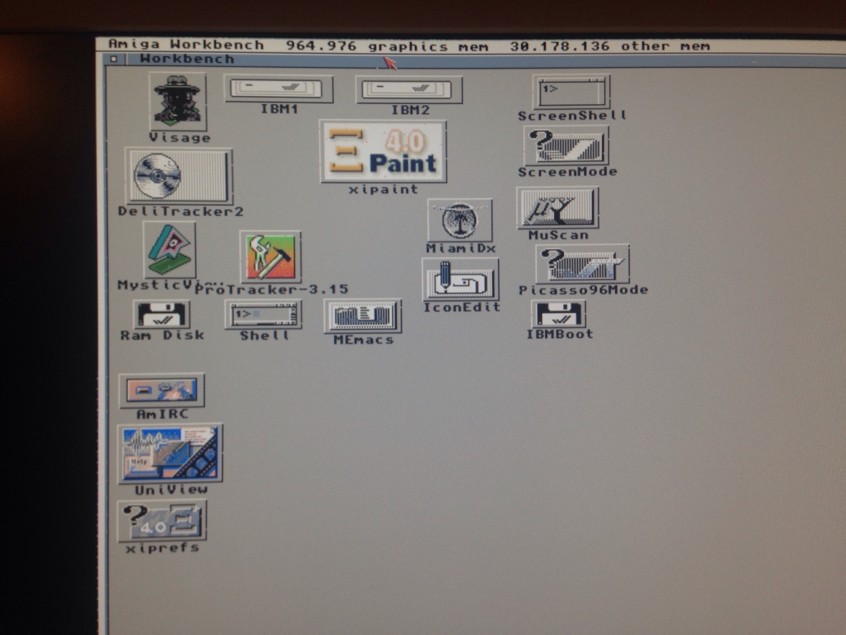
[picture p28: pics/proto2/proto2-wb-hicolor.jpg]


UniView displaying a JPEG (from Hood By Air show):

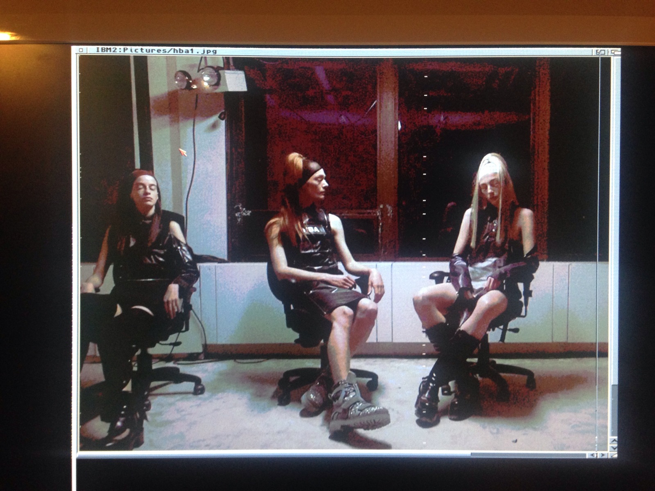
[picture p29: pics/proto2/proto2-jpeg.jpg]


Obligatory shot of Doom:

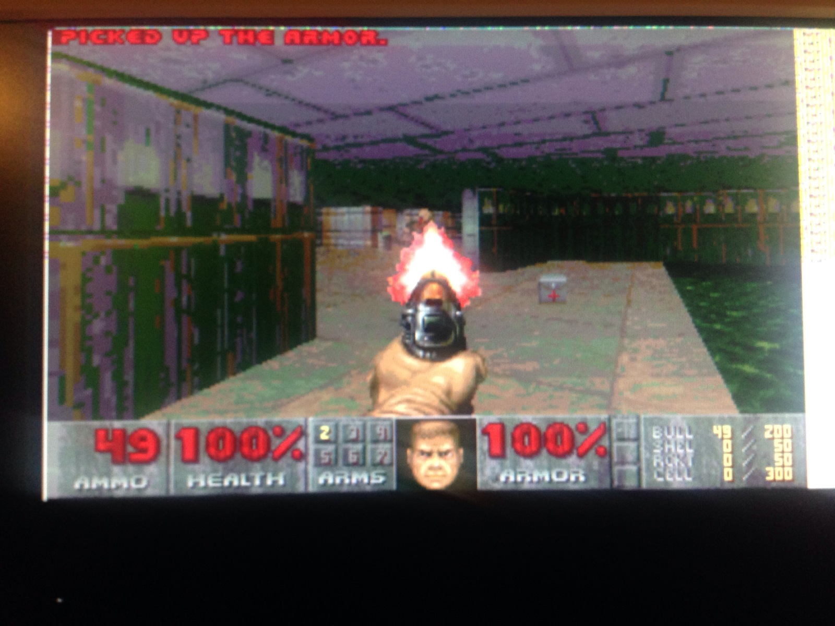
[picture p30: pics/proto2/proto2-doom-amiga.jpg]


## TODO

I will make one more version of the card supporting a reliable manufacturer's FPGA board and the following improvements. If you have the knowledge / tips on how to tackle any of these, feel free to contact me or submit pull requests:

- Fix the remaining noise in writes/reads
- Wait states via XRDY signal: If READ timing cannot be guaranteed or the WRITE queue is full, the card could ask the host CPU to wait by asserting XRDY, avoiding loss of data.
- Switching resolutions and color modes including true color (24 bit)
- Basic hardware block copy and rect filling support
- Digitizing and scandoubling the native amiga video for HDMI output
- Design a proper metal slot plate for connectors

## How can I build or buy a VA2000 board?

I still have to finish the "release" version of the board including the above fixes. I plan to offer preassembled versions and/or construction kits at reasonable prices. If you want to reserve a board, please send me an email to lukas@mntmn.com including "VA2000" in the subject.

All aspects of the project (schematics, PCB, verilog, driver sources) are or will be published as open source under the MIT license, so you are free to produce your own clones of the board.

## Sources, References, Thanks

Special thanks to Martin Åberg for sharing his "GRETA" Amiga 500 expansion sources (https://github.com/endofexclusive/greta). It inspired me to include bus signal synchronizers and helped with AUTOCONF.

Special thanks to Mike Field, his SDRAM and HDMI sources saved me a lot of time:
- http://hamsterworks.co.nz/mediawiki/index.php/Simple_SDRAM_Controller
- http://hamsterworks.co.nz/mediawiki/index.php/Dvid_test

Amiga Hardware Manual: http://amigadev.elowar.com/read/ADCD_2.1/Hardware_Manual_guide/node0000.html

KiCad Open Source Super Awesome EDA: http://kicad.org

Thanks to the CommodoreAmiga group on Facebook and thanks to Sebastian Hartmann, Adrian Kaiser, Daniel Zahn, Greta Melnik for inspiration and motivation. Thanks to Jeri Ellsworth for inspiring me to learn Verilog.

Greetings to kipper2k/majsta/BigGun over at the Vampire project!

## Copyright / License

(C)2016 Lukas F. Hartmann (@mntmn) / MNT Media and Technology UG.
http://mntmn.com
https://twitter.com/mntmn

Permission is hereby granted, free of charge, to any person obtaining a copy of this software and associated documentation files (the "Software"), to deal in the Software without restriction, including without limitation the rights to use, copy, modify, merge, publish, distribute, sublicense, and/or sell copies of the Software, and to permit persons to whom the Software is furnished to do so, subject to the following conditions:

The above copyright notice and this permission notice shall be included in all copies or substantial portions of the Software.

THE SOFTWARE IS PROVIDED "AS IS", WITHOUT WARRANTY OF ANY KIND, EXPRESS OR IMPLIED, INCLUDING BUT NOT LIMITED TO THE WARRANTIES OF MERCHANTABILITY, FITNESS FOR A PARTICULAR PURPOSE AND NONINFRINGEMENT. IN NO EVENT SHALL THE AUTHORS OR COPYRIGHT HOLDERS BE LIABLE FOR ANY CLAIM, DAMAGES OR OTHER LIABILITY, WHETHER IN AN ACTION OF CONTRACT, TORT OR OTHERWISE, ARISING FROM, OUT OF OR IN CONNECTION WITH THE SOFTWARE OR THE USE OR OTHER DEALINGS IN THE SOFTWARE.

My dog Tina "helping" me debugging:

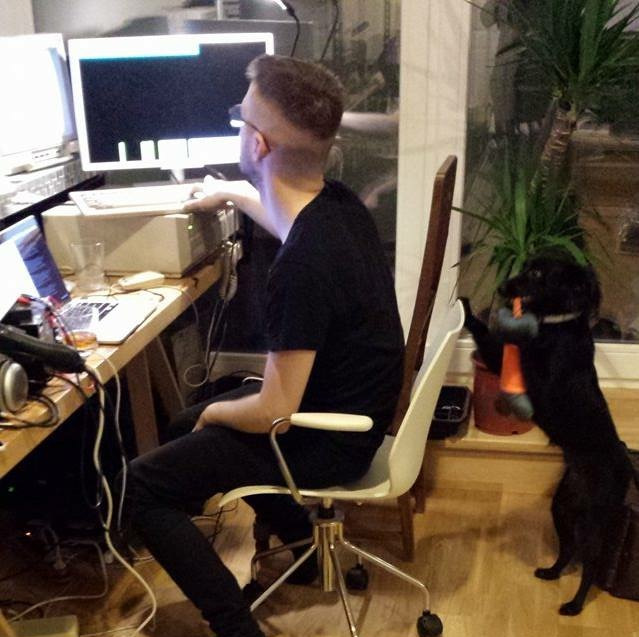
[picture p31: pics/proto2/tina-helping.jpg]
My dog Tina helping me


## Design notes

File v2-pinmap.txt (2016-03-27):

P1 E (top)

1 -    3v3
2 A15  E1
3 A14  E3
4 A13  E5
5 -    GND
6 A2   E7
7 A6   E9
8 A5   E11

P2 E (bottom)

1 -      GND
2 /BERR  E0
3 /RST   E2
4 E7M    E4
5 -      3v3
6 A23    E6
7 A22    E8
8 A17    E10

P4 A (top)

1 D3   A1
2 D5   A3
3 D6   A5
4 -    3v3
5 D8   A7
6 D9   A9
7 D10  A11
8 -    GND

P6 A (bottom)

1 D1   A0
2 D0   A2
3 D11  A4
4 -    GND
5 D13  A6
6 D14  A8
7 D15  A10
8 -    3v3

P5 F (top)

1 -     3v3
2 A11   F1
3 A10   F3
4 A9    F5
5 -     GND
6 A7    F7
7 A3    F9
8 A4    F11

P3 F (bottom)

1 -     GND
2 /UDS  F0
3 /LDS  F2
4 READ  F4
5 -     3v3
6 A20   F6
7 A19   F8
8 A18   F10

P14 B (top)

1 /AS     B1
2 A21     B3
3 A12     B5
4 -       3V3
5 A8      B7
6 /CFGIN  B9
7 DOE     B11
8 -       GND

P13 B (bottom)

1 D2      B0
2 D12     B2
3 D4      B4
4 -       GND
5 D7      B6
6 A16     B8
7 A1      B10
8 -       3V3

P16 (out) D

1 /CFGOUT
2 /SLAVEn
3 DIR

--------------
vga test
--------------

PORT C

C1  R
C3  G
C5  B
C0  Vsync
C1  Hsync
C4  -
GND GND

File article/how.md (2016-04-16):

# How I decided to make a graphics card for my Amiga 2000

Somewhere in the middle of 2015 I revived my old A500 and acquired again an A1200, the computer I learned C++ and the basics of web programming on in the late 90s. I also played lots of fantastic Amiga games back in the day, made my first music in ProTracker and my first digital graphics in Deluxe Paint. Re-experiencing the old system that was so ahead of its time again made me curious about Commodore's history and especially about the late, big and ambitious Amiga models (A3000, A4000). This coincided with Amiga's 30th anniversary. A lot of new interviews with the original team(s) popped up, including Dave Haynie, who designed most of the A2000 and the Zorro Bus.

I checked eBay for the "big" Amigas I never had, expecting them to be cheap, but found out that these boxes had turned into valuable collector's items. At the same time, A2000s were (and still are) affordable, so I chose to get one and put a 68040 and a SCSI card in it. But the system couldn't realize it's full potential; in the 90s you could already get, for example, a "Picasso" graphics card that could do VGA (and higher) resolutions at 16 or 24bit color depth. Nowadays, these totally outdated cards are rare and sold for ridiculous prices. My A2000 was stuck with 640x256 PAL resolution, 64 colors (ignoring HAM) or headache-inducing interlaced modes. 

Because of my work with Microcontrollers, writing a low-level OS for Raspberry Pi and my interest in low-level computer architectures in general, I decided in October 2015 in a feat of madness: "I'll just make my own graphics card. How hard can it be?"

It turned out to be a very, very challenging project, but luckily I came much further than I expected. On the way, I had to learn how to design a PCB and get it manufactured, how to work with SMD parts, how to program in Verilog and synthesize code for an FPGA, how SDRAM and DVI/HDMI work (or how to get them to do at least something). I also had to find out how to write a driver for the sadly closed/undocumented Picasso96 "retargetable" graphics stack for AmigaOS 3.

The Amiga is probably the last 32-bit personal computer that is fully understood, documented and hackable. Both its hardware and software contain many gems of engineering and design. I hope that one day, we can have a simple but powerful modern computer that is at the same time as hackable and friendly as the Amiga was.

## The "engine": FPGA and SDRAM

As a platform for my first attempt (ultimately a failure) I chose the Papilio Pro dev board, which has a Xilinx Spartan 6 FPGA and a few megabytes of  SDRAM connected to it. It also has two pin headers that break out some of the general purpose input/output pins of the Spartan. I thought, OK; I could use the RAM to store the image (a framebuffer), and run a loop that goes through all the columns and rows of the picture in the correct speed and just output the bytes from the RAM to R,G and B output lines. I did this before with little Atmel microcontrollers – "bit-banging" a VGA image directly from the CPU – so I knew it was possible. I just didn't know that SDRAM (synchronous dynamic RAM) was a lot more complex to use than the integrated SRAM (static RAM) of common microcontrollers.

 [diagram and explanation of SDRAM timing]

I connected an Arduino to the Papilio and used it to send a few address bits and an "on/off" bit to toggle pixels in the framebuffer black or white. This contraption was able to draw basic fonts on my VGA display, and they were successfully kept in the SDRAM. 

The next step was connecting the FPGA+display part to the Amiga 2000.

## Zorro II: Reads and Writes

The original Amiga Hardware Manuals helped me understand the Zorro II bus. It is basically an extension (arbitrated by a bus controller chip) of the pins of the Motorola 68000 CPU. The 68k is extensively studied and documented. I understood that I needed a mechanism that would allow the 68k CPU to write data (pixels) to the graphics card's RAM and another for reading back parts of the screen (for scrolling and moving around things).

68000 Read Cycle

So I fired up the open source circuit design tool KiCad and started some schematics. The first task was to define the Zorro port as a component with a whopping 100 pins. Of course I made a lot of little mistakes at first and I had no idea why one would need so many different signals. It turned out that I only needed a subset of the pins to get my job done:

1. Address Bus (A1-A23)
2. Data Bus (D0-D15)
3. Upper and Lower "Data Strobes" (UDS / LDS)
4. READ, /AS, DOE, signals which the Amiga uses to communicate if it wants to read or write, if it presents a valid address and if it expects a device to send data.
5. Power (5V, GND)
6. Autoconf (/CFGIN, /CFGOUT)

68000 Read Cycle

I figured that I needed to connect most of these signals to the FPGA and then write another loop in Verilog that would interpret the Amiga's bus commands and act on them (store the data given on the bus in the RAM or return stuff from the RAM). 

On the other side of the FPGA, I decided to place an Analog Devices DAC(XYZ) digital to analog converter chip that would generate the analog R, G and B channels for the VGA port from the bits coming from the framebuffer.

Analog Devices ADV7125

The next hurdle appeared: The Spartan communicate with modern 3.3V logic levels, but the Amiga used legacy 5V signals. So I needed to put voltage translators (also called level shifters) between the Zorro and the FPGA pins. I decided to split the signals into bundles of 8 and use six 8-bit "auto-direction-sensing" TXS0108 chips.

Texas Instruments TXS0108 

## Mistake: Trying to be too smart

I then realized that the Papilio, the FPGA board I had, didn't have enough I/O pins to connect to the 48 Zorro signals and the 16 (?) pins required for the VGA DAC output. Actually, it had a lot less pins. So I made a huge mistake and decided to use two 16-bit port switching chips and "select" on the fly a window of the Zorro pins that would be relevant at each state of my bus communication loop; I thought I didn't need to access the data pins at the same time as the address pins and because the FPGA runs at a much higher frequency than the Zorro bus, I could first read one part of the address, switch one of the switches via a control pin and then quickly read the other part to get the whole address.

Failed Prototype 1 Schematics 

After drawing up a few versions of the schematics and collecting the fitting footprints for the components from various GitHub repositories, I imported them into KiCad's PCB design tool and started drawing the actual circuit board. I had no experience doing this, so I worked through tutorials or just looked at how other people were solving their board design problems. Finally, I uploaded the exported "Gerber" files to DirtyPCBs.com, ordered, waited 8 weeks and nothing happened. I made the mistake of choosing the AirMail option, which has no tracking, and the package was lost. After getting no support from DirtyPCB, I chose to try again, this time selecting the DHL option with tracking and finally got my first ever printed circuit boards in the mail around 10 days later! By now, it was the middle of January 2016.

Prototype 1 PCBs

In parallel, I ordered the required chips and parts from Mouser; luckily I had gotten most of the footprints right, except for one logic gate IC that turned out to be a mistake anyway. I got to work and tried to solder my first SMD ICs using my trusted ERSA iron. 

Failed Prototype 1 Board 

It turned out I had made a number of critical mistakes in designing the boards: all of the voltage translators' OE pins were tied to GND when they should have had 3.3V, so they required manual bending and patching of the OE leg (yellow cables in the picture). I accidentally switched 3.3V and GND pins on the FPGA carrier headers, so I needed to reroute them with wires on the back. Because I misinterpreted the Multiplexer IC's datasheet, I also planned for a negating Logic IC on their SEL pins which was totaly wrong. In the end I had to solder bridges instead of placing the 74LS04. 

After fighting through all of these issues and burning through a few boards, I finally gut some results. As a first debugging step, I wrote a poor man's logic analyzer in Verilog that would record 640 cycles of all the Zorro Bus signals to FPGA registers (BRAM) and dump them as colorful lines on the VGA screen. This turned out to be a helpful instrument. I wrote a very simple program in 68k assembler for the Amiga that would read – in an endless loop – a word from address $e80000 and write it to $dff180 (a background color register). I made a boot floppy that would run the program, put my card in the A2000, flashed the code and turned everything on.

Prototype 1 Zorro Bus Analyzer 1 

The first 5 longer, stretched rows in this picture are the signals DOE, READ, /UDS, /AS and E7M (Amiga 7Mhz Clock) sampled at 100 Mhz/Column, so the whole picture displays a time sample of 6400ns (nanoseconds) or 6.4ms (milliseconds).

The following lines on the grid represent the Address bits A23-A1 in descending order. A0 does not exist; the 68000 selects an upper, lower or both bytes (word access) using /UDS and /LDS instead.

The address signals have regular little chops in them; this is a nasty side effect of switching the multiplexers. You can also see that address bit A9 is constantly turned on, probably due to a soldering error. At least it's possible to see the 68000's read and subsequent write accesses (the only hole in the READ row, second from the top). Ignoring the broken pins A9 and A17, the READ occurs as expected on address binary 111010000000000000000000 and the WRITE on 0b110111111111000110000000. Due to the constant noise and other random failures, I couldn't reliably get the Amiga to reliably read from my card, but it worked at least sometimes, giving me hope.

After a few nights of trying to fix this very unstable system, I gave up and went back to the drawing board.

## Redesign and Breakthrough

My new strategy was:
1. Make the board much simpler, focus on voltage translation and find a FPGA board with enough IOs
2. Get a decent (de-)soldering station and learn a better SMD soldering technique

Prototype 2 Schematics
Prototype 2 Design

To solve point 2, I ordered a Yihua 853D on Aliexpress and experimented with hot air solder paste soldering (not a success for me, the results were quite messy). I then watched Sparky's SMD soldering techniques again: https://www.youtube.com/watch?v=z7Tu8NXu5UA
To my surprise, using the "dragging" technique with plenty of flux and a chisel tip (Sparky recommends a "gullwing" tip) at around 270 Celsius yielded the cleanest results I had so far.

Drag Soldered Voltage Translators

Prototype 2 with miniSpartan mounted

Prototype 2 Clean Signals

Prototype 2 Assembler Mouse Test

Prototype 2 Picture Load Test

## Picasso96: Writing a Driver

Picasso96 was one of two competing systems (the other being CyberGraphX) integrating graphics cards into the Amiga "Monitor" Device system. P96 also ships an "emulation.library" that patches all system windowing and drawing functions and redirect the legacy bit-planar based output to the new "chunky" pixel formats. After the death of Commodore and the Amiga market, Village Tronic, the authors of P96, disappeared. It's unclear where the sources and internal documentation ended up.

Prototype 2 first Amiga Workbench Screen
Prototype 2 first Amiga Doom Screen

## Fixing READs

Prototype 2 Workbench READ noise
Prototype 2 READ Problems
Prototype 2 better READs

## Fixing the Colors

Prototype 2 Amiga NetSurf
Prototype 2 Amiga HiColor Problems
Prototype 2 Amiga HiColor Triangle

Prototype 2 Workbench 65535 Colors
Prototype 2 Workbench 65535 Colors
Prototype 2 Workbench 65535 Colors

## Problems to solve

- read arbitration
- XRDY (wait states)

## FAQ

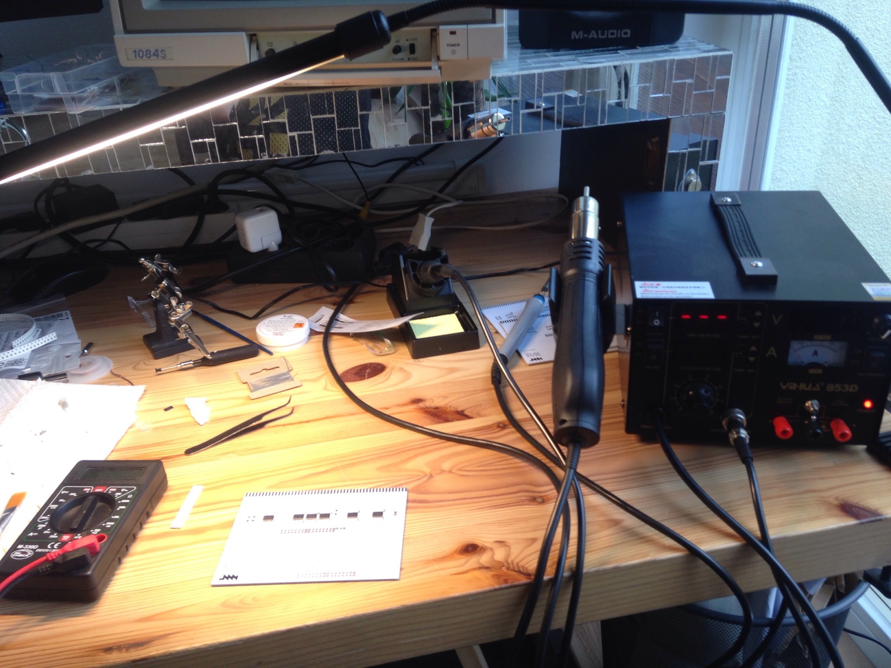
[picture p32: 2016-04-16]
pics/proto2/yihua-desk.jpg

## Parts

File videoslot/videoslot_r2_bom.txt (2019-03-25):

U1 U2: SN74LVC8T245PWR 8-Bit Dual-Supply Bus Xcvr
C1 C2 C3 C4: Murata GRM21BR71E104KA01L 0.1uF 0805
P1: Harwin M20-9960645 06 SIL HORIZONTAL PIN HEADER GOLD HT
P2: Harwin M20-9700645 06+06 DIL HORIZONTAL PIN HEADER GOLD HT
P3: Harwin M20-9981845 18+18 DIL VERTICAL PIN HEADER GOLD HT

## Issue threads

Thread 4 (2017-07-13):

SD Card Fails to Format FFS

madgrizzle, 2017-07-13:
Followed instructions with only one change:
FileSystem = L:FastFileSystem

Rebooted, issued:
mount sd0:
format drive sd0: name "sdcard" quick

Computer returns with "Initializing..." followed by a "seek error".  Per a suggestion on amiga.org, I added:
DosType = 0x444f5303

After issuing format command, responds with a "*" instead of the seek error.

LooZee, 2019-02-07:
Same problem with PFS3 and FFS.
HDToolBox sees the device, but initializing the card hangs.
Formatting doesn't work as previously described by madgrizzle.
Tried cards from Samsung, Intenso and SanDisk in 2GB, 4GB, 8GB and 64GB sizes.

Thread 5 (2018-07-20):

Software failure during boot on 1.9.0 beta 2

robdaemon, 2018-07-20:
After updating to the 1.9.0b2 firmware (Tested both the Z2 75 mhz clock 2 mb mode, and Z2 100 mhz clock firmwares) and installing the new drivers, I get a software failure on startup:

FILE0
Program failed (error #80000006)
Suspend / Reboot

My configuration:
Amiga 2000
A2630 with BigRAM 2630
Buddha IDE
VA2000 + VA2000CX

I did not see this error with the 1.9.0b2 firmware and 1.8.5 driver combination.

robdaemon, 2018-07-20:
Okay, this is a false alarm. Somehow one of my device driver files in Devs:DOSDrivers got corrupted. It just appeared when I rebooted immediately after updating the VA2000 drivers.

mntmn, 2018-07-20:
Ahh, thanks for the clarification. This is exactly what I suspected.

Cheers
Lukas

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

Closed 2018-07-20.

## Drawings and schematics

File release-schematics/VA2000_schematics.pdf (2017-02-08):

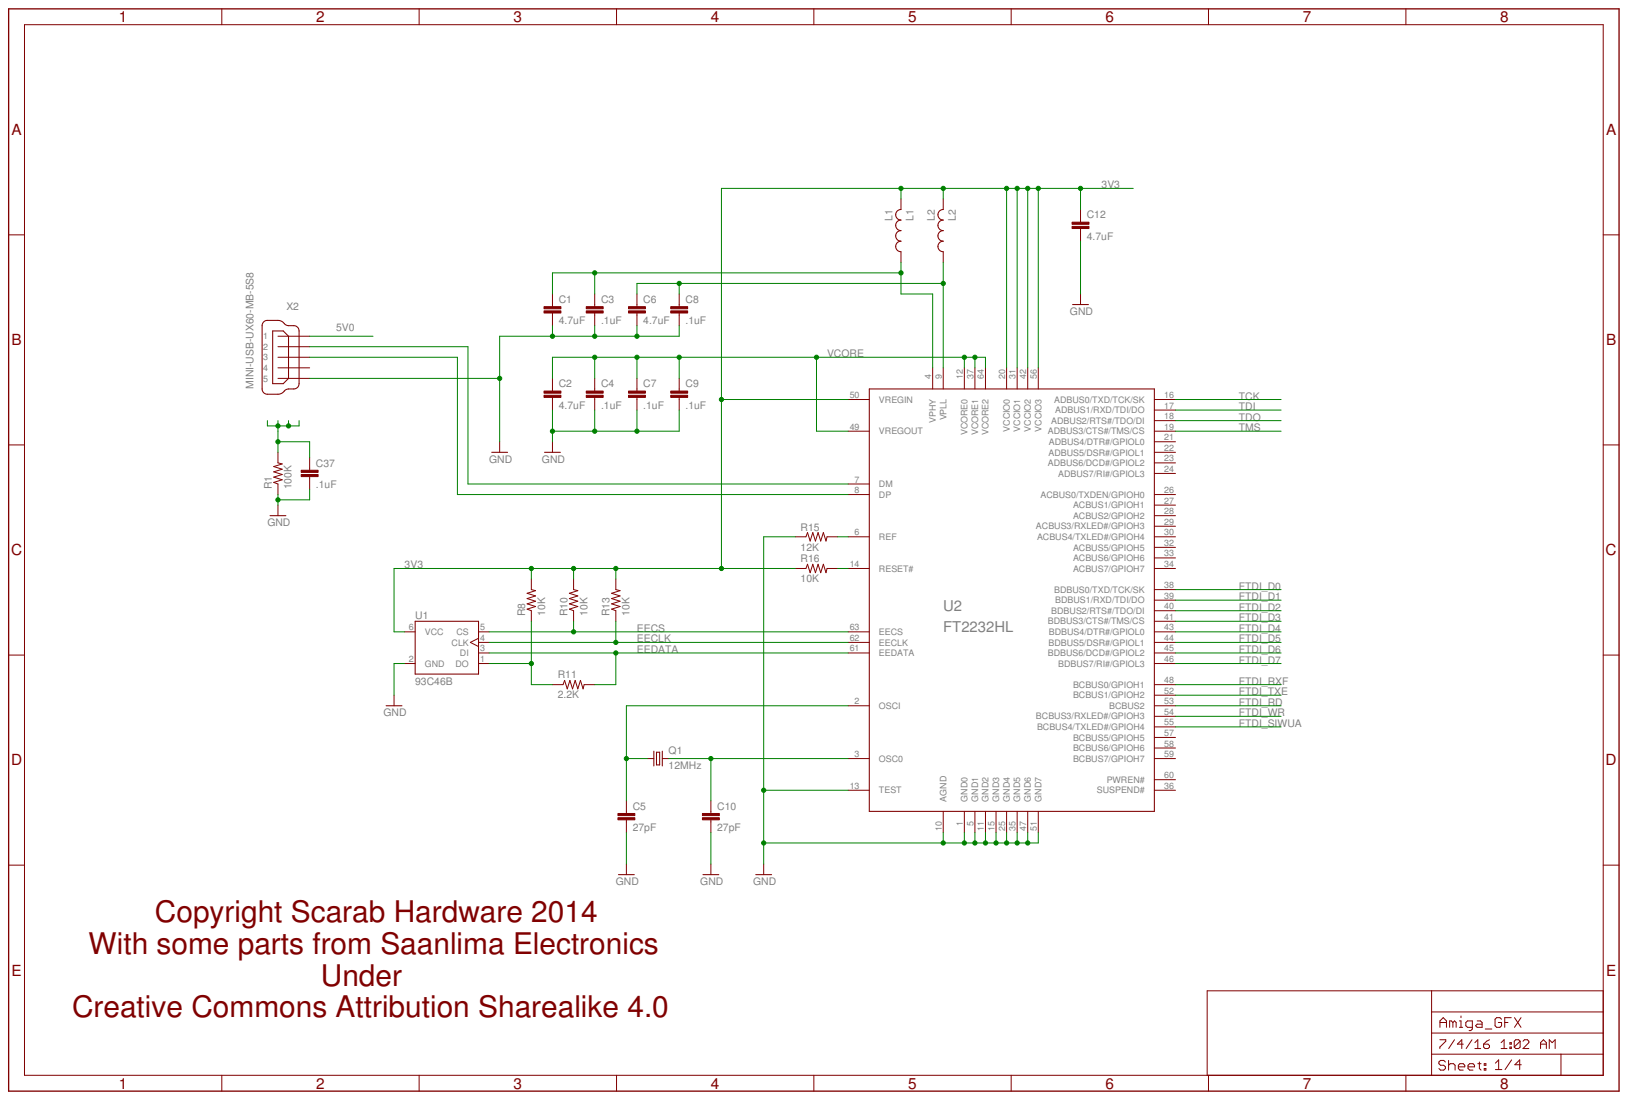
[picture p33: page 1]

Copyright Scarab Hardware 2014
With some parts from Saanlima Electronics
Creative Commons Attribution Sharealike 4.0

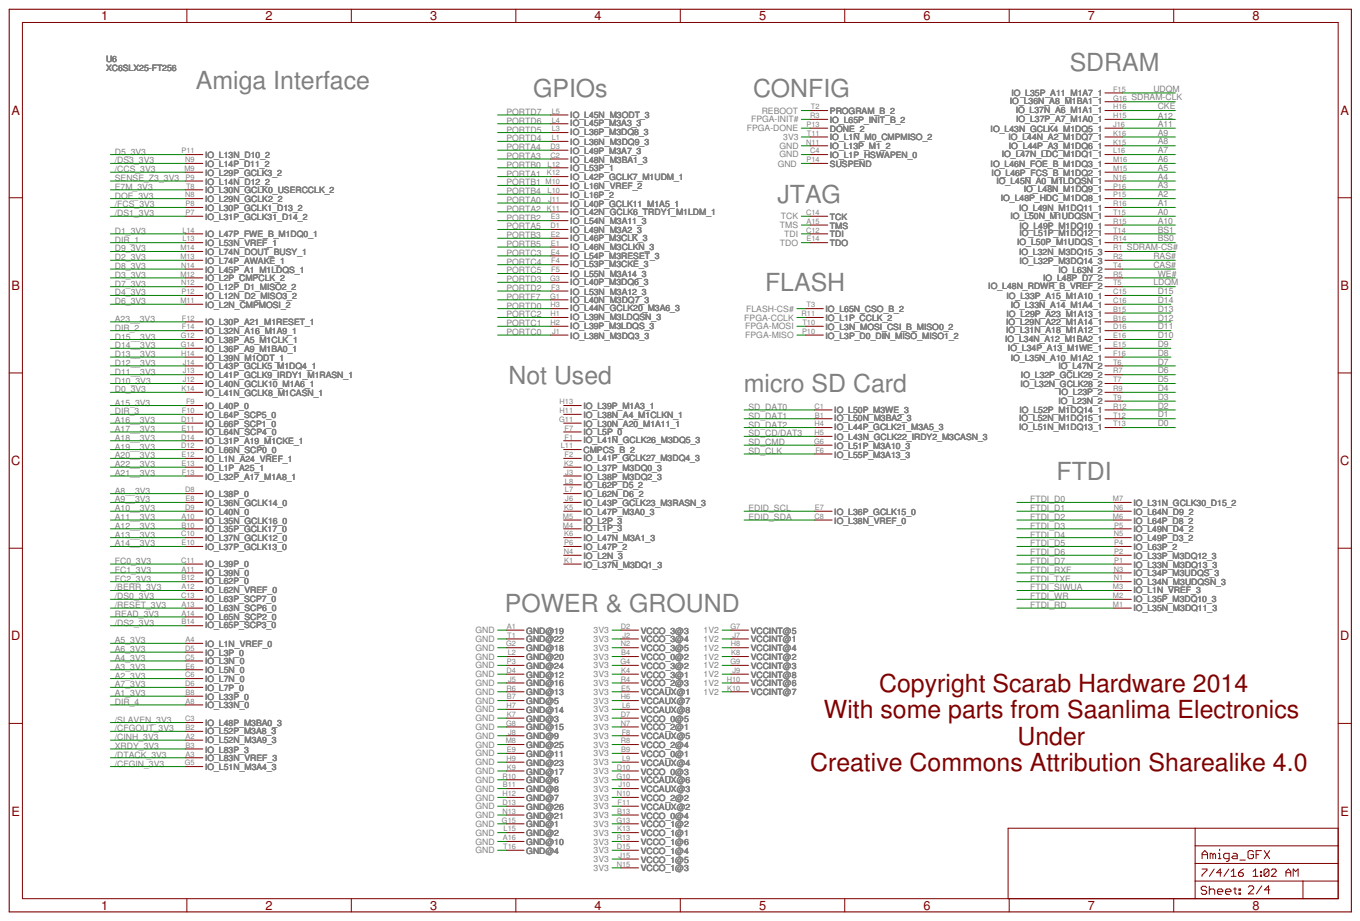
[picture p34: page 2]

VCCINT@8
With some parts from Saanlima Electronics
Creative Commons Attribution Sharealike 4.0

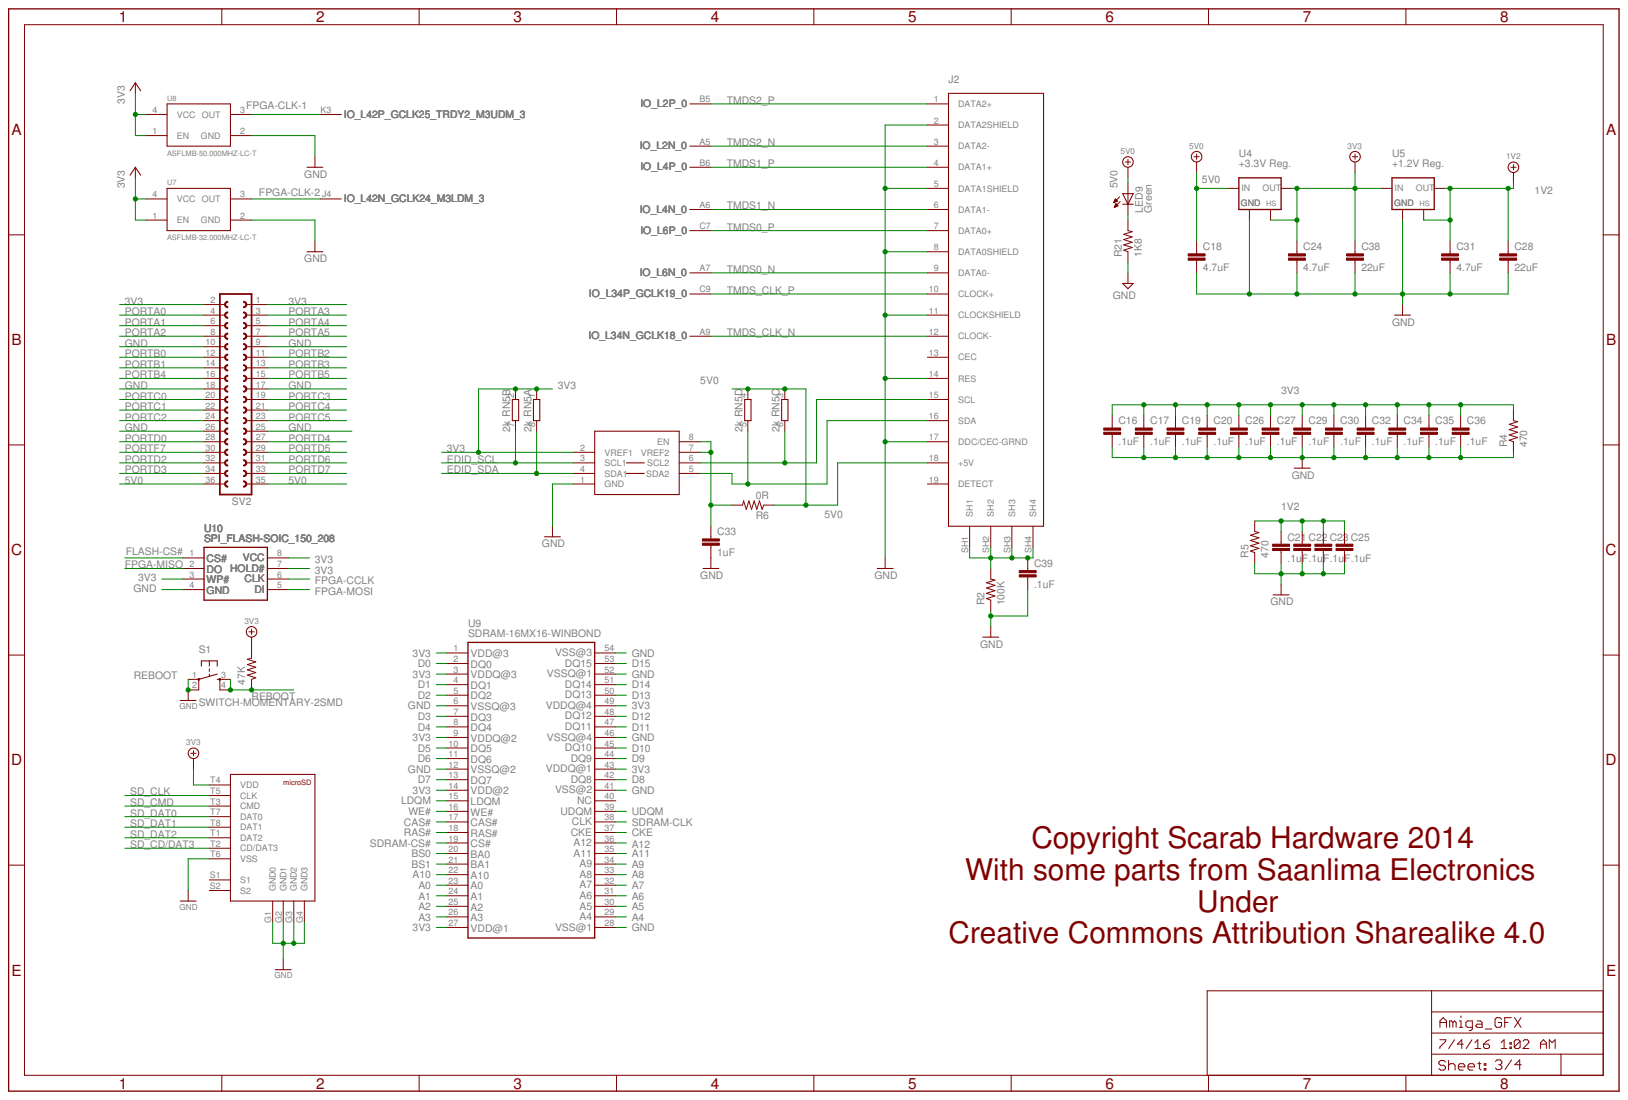
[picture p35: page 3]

IN OUT GND HS U4

IN OUT GND HS U5

Copyright Scarab Hardware 2014
With some parts from Saanlima Electronics
Creative Commons Attribution Sharealike 4.0

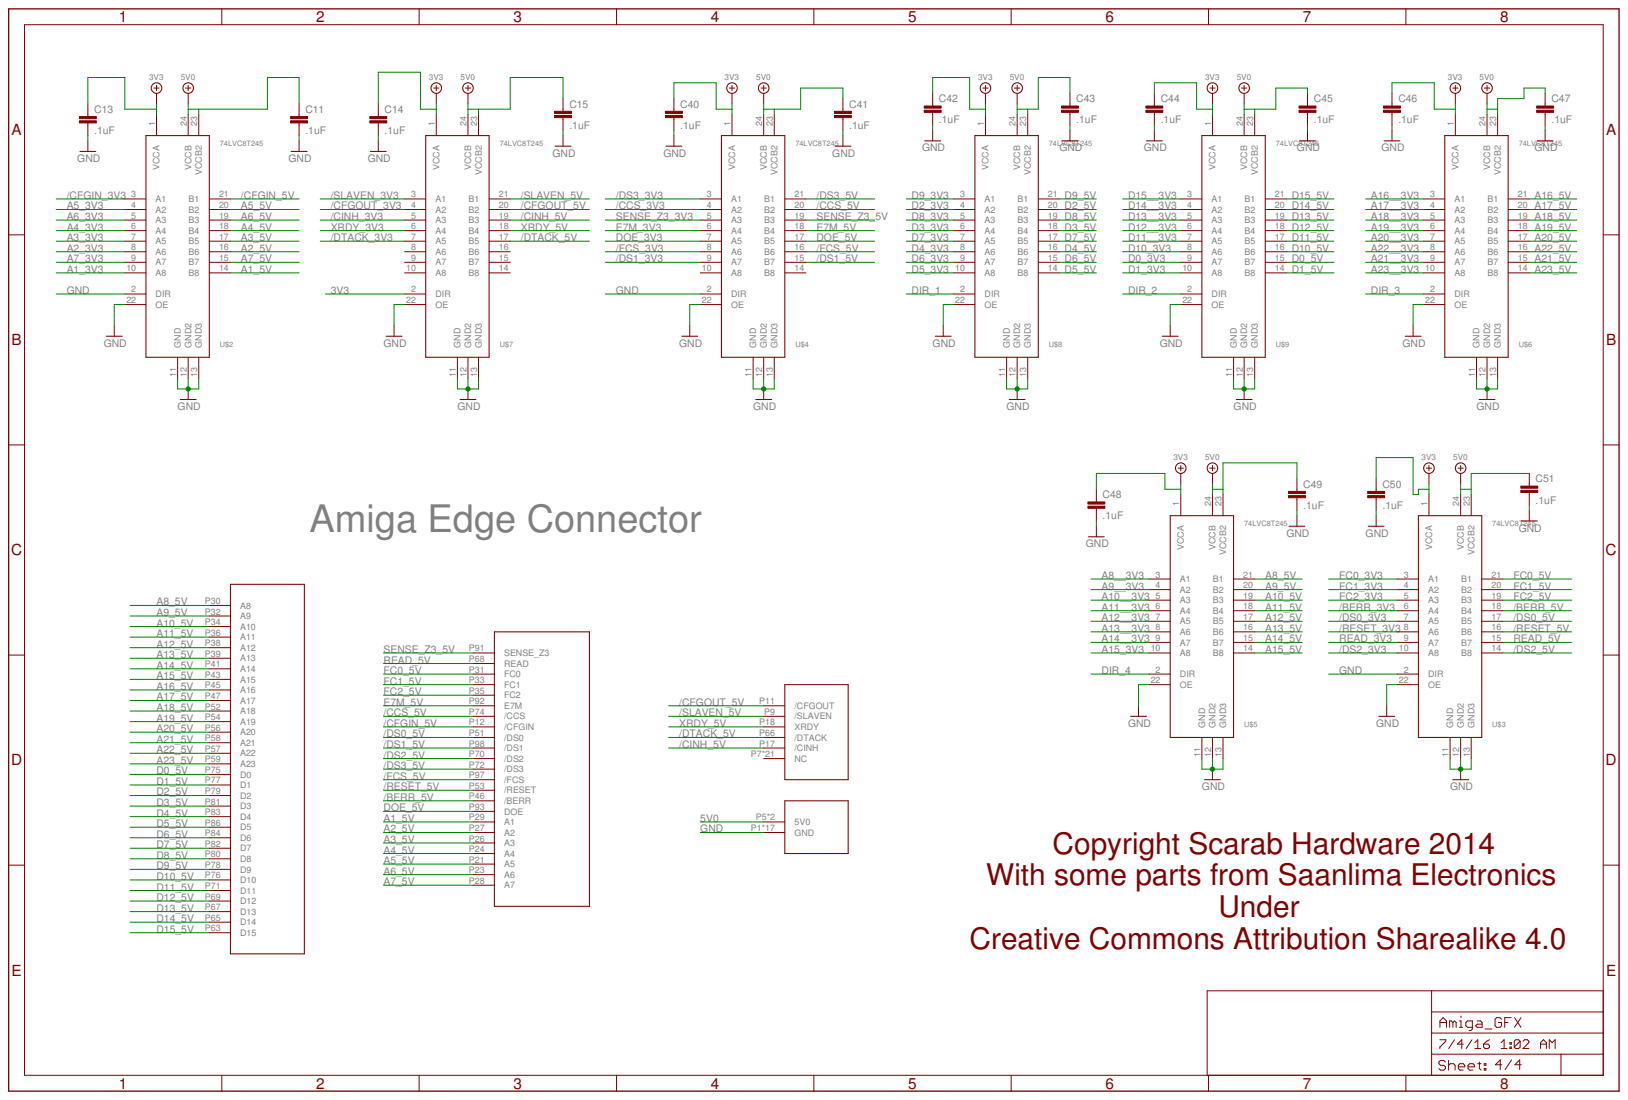
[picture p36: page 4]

Copyright Scarab Hardware 2014
With some parts from Saanlima Electronics
Creative Commons Attribution Sharealike 4.0

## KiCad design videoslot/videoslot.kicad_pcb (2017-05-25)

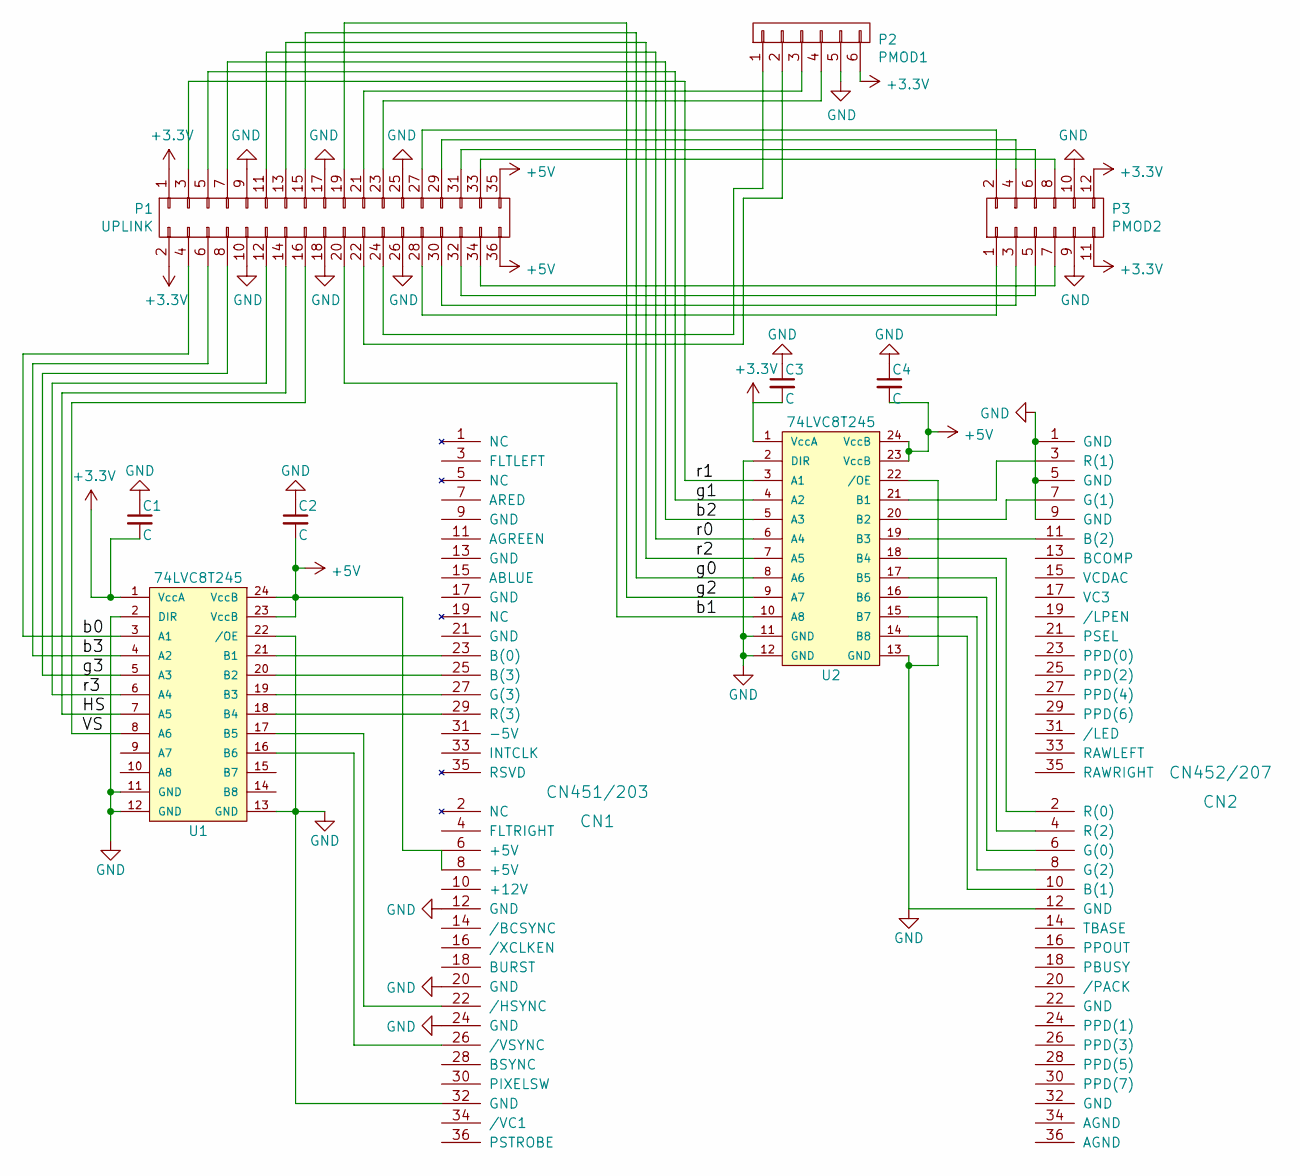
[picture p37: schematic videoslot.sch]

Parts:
C1, C2, C3, C4: C; C_0805_HandSoldering
CN1: CN451/203; CN451
CN2: CN452/207; CN452
P1: UPLINK; Pin_Header_Straight_2x18_Pitch2.54mm
P2: PMOD1; Pin_Header_Angled_1x06_Pitch2.54mm
P3: PMOD2; Pin_Header_Angled_2x06_Pitch2.54mm
U1, U2: 74LVC8T245; TSSOP24-44

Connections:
+3V3: C1.2, C3.2, P1.1, P1.2, P2.6, P3.11, P3.12, U1.1 (VccA), U2.1 (VccA)
+5V: C2.2, C4.2, CN1.6 (+5V), CN1.8 (+5V), P1.35, P1.36, U1.23 (VccB), U1.24 (VccB), U2.23 (VccB), U2.24 (VccB)
/HS: P1.14, U1.7 (A5)
/VS: P1.16, U1.8 (A6)
/b0: P1.4, U1.3 (A1)
/b1: P1.20, U2.10 (A8)
/b2: P1.7, U2.5 (A3)
/b3: P1.6, U1.4 (A2)
/g0: P1.15, U2.8 (A6)
/g1: P1.5, U2.4 (A2)
/g2: P1.19, U2.9 (A7)
/g3: P1.8, U1.5 (A3)
/r0: P1.11, U2.6 (A4)
/r1: P1.3, U2.3 (A1)
/r2: P1.13, U2.7 (A5)
/r3: P1.12, U1.6 (A4)
GND: C1.1, C2.1, C3.1, C4.1, CN1.12 (GND), CN1.20 (GND), CN1.24 (GND), CN1.32 (GND), CN2.1 (GND), CN2.5 (GND), CN2.9 (GND), CN2.12 (GND), P1.9, P1.10, P1.17, P1.18, P1.25, P1.26, P2.5, P3.9, P3.10, U1.2 (DIR), U1.11 (GND), U1.12 (GND), U1.13 (GND), U1.22 (/OE), U2.2 (DIR), U2.11 (GND), U2.12 (GND), U2.13 (GND), U2.22 (/OE)
unnamed: CN1.22 (/HSYNC), U1.17 (B5)
unnamed: CN1.23 (B(0)), U1.21 (B1)
unnamed: CN1.25 (B(3)), U1.20 (B2)
unnamed: CN1.26 (/VSYNC), U1.16 (B6)
unnamed: CN1.27 (G(3)), U1.19 (B3)
unnamed: CN1.29 (R(3)), U1.18 (B4)
unnamed: CN2.2 (R(0)), U2.18 (B4)
unnamed: CN2.3 (R(1)), U2.21 (B1)
unnamed: CN2.4 (R(2)), U2.17 (B5)
unnamed: CN2.6 (G(0)), U2.16 (B6)
unnamed: CN2.7 (G(1)), U2.20 (B2)
unnamed: CN2.8 (G(2)), U2.15 (B7)
unnamed: CN2.10 (B(1)), U2.14 (B8)
unnamed: CN2.11 (B(2)), U2.19 (B3)
unnamed: P1.21, P2.3
unnamed: P1.22, P2.2
unnamed: P1.23, P2.4
unnamed: P1.24, P2.1
unnamed: P1.27, P3.2
unnamed: P1.28, P3.1
unnamed: P1.29, P3.4
unnamed: P1.30, P3.3
unnamed: P1.31, P3.6
unnamed: P1.32, P3.5
unnamed: P1.33, P3.8
unnamed: P1.34, P3.7

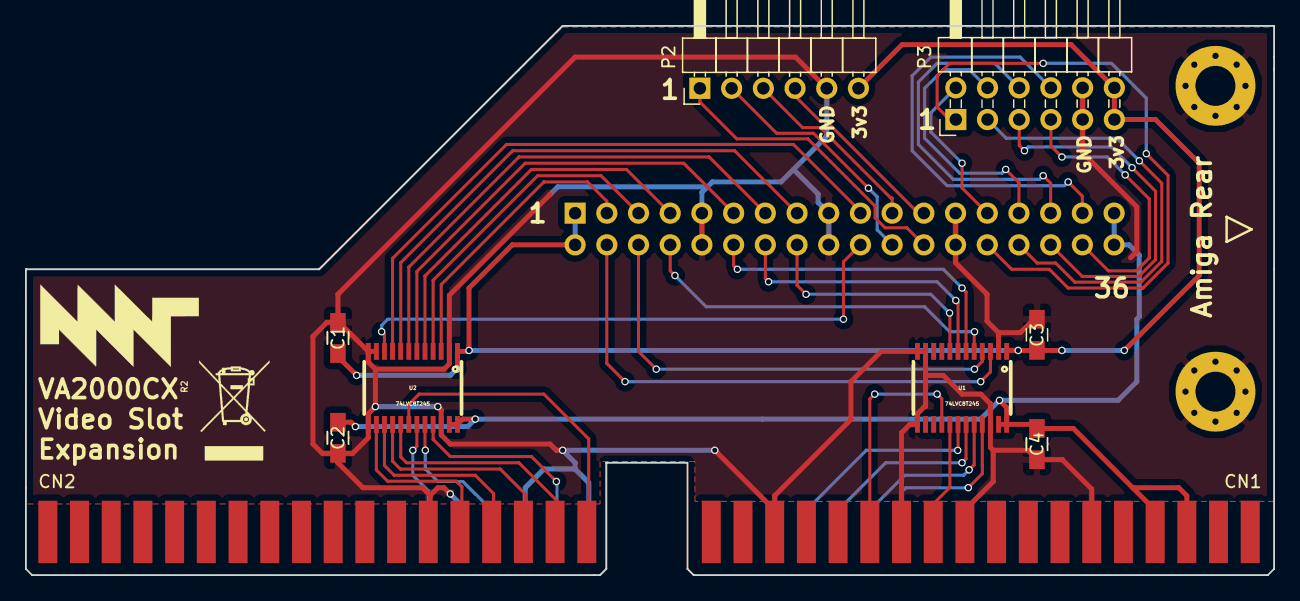
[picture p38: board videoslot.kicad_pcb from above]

Board: 2 copper layers, 100.0 x 44.0 mm, 11 parts (1 on the bottom side), 43 nets.

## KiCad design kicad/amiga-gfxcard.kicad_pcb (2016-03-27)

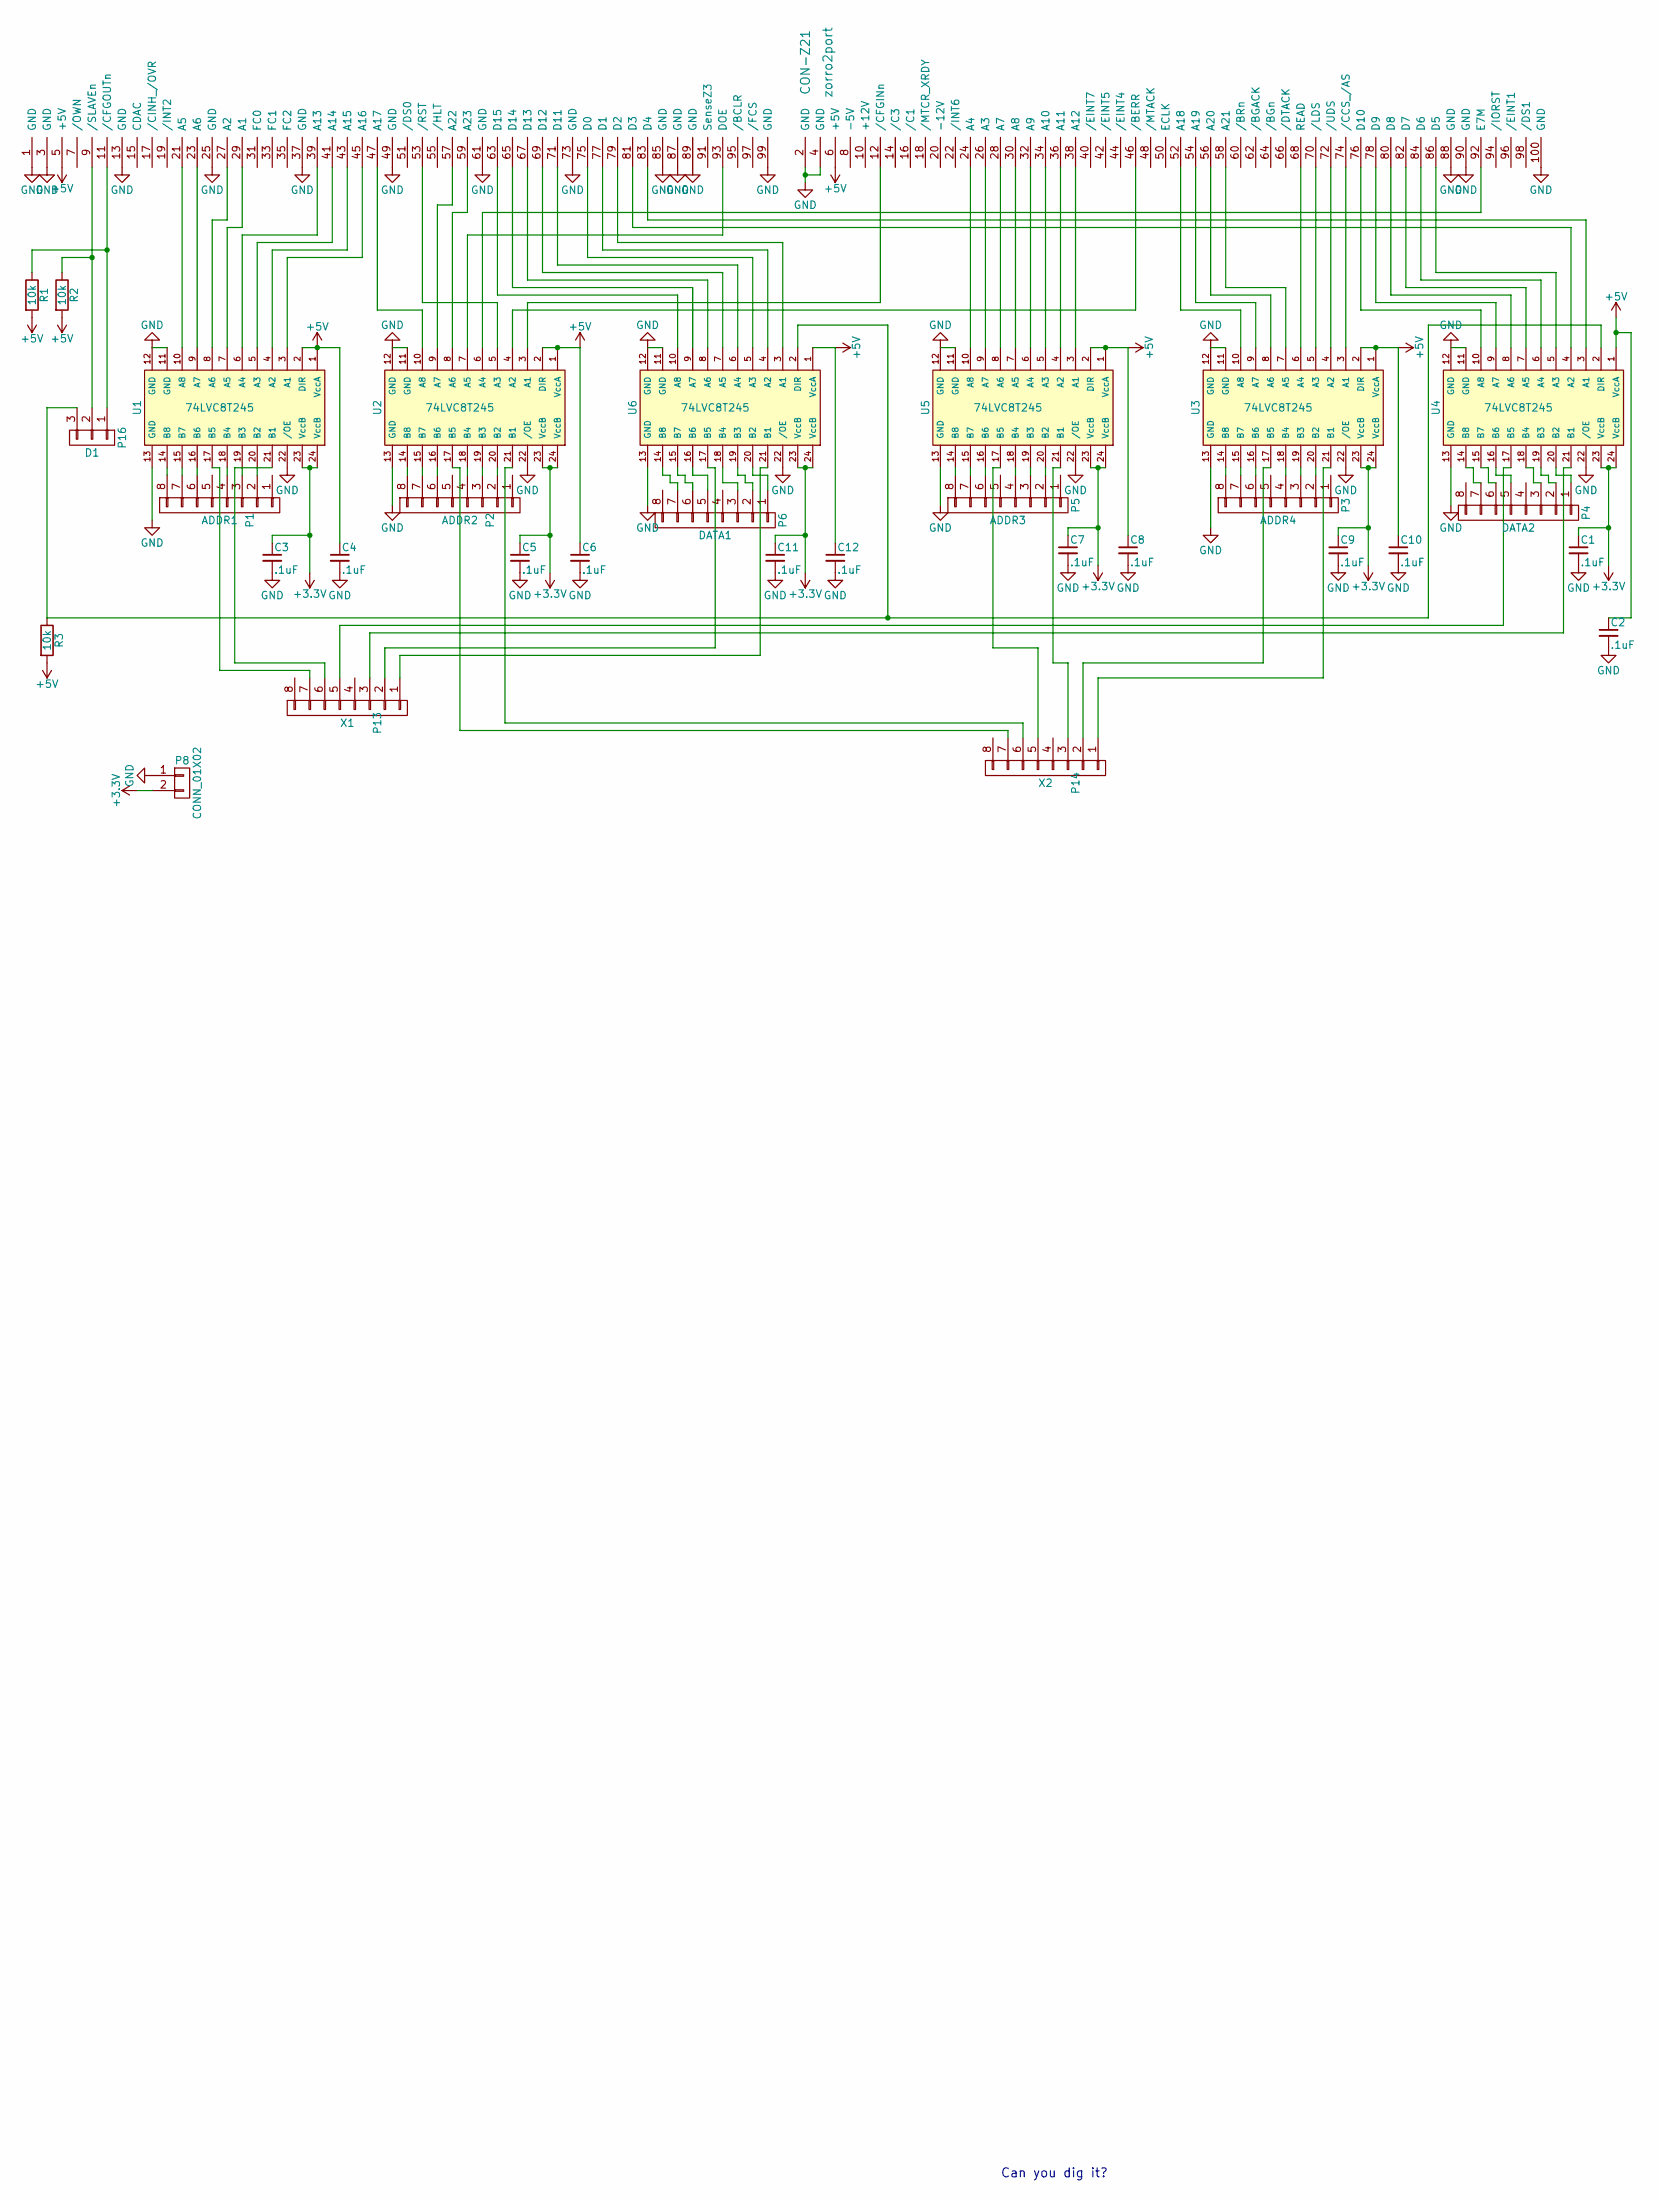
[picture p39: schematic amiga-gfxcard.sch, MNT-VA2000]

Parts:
C1, C2, C3, C4, C5, C6, C7, C8, C9, C10, C11, C12: .1uF; C_0805_HandSoldering
CON-Z21: zorro2port; zorro2card
P1: ADDR1; Pin_Header_Straight_1x08
P2: ADDR2; Pin_Header_Straight_1x08
P3: ADDR4; Pin_Header_Straight_1x08
P4: DATA2; Pin_Header_Straight_1x08
P5: ADDR3; Pin_Header_Straight_1x08
P6: DATA1; Pin_Header_Straight_1x08
P8: CONN_01X02; Pin_Header_Straight_1x02
P13: X1; Pin_Header_Straight_1x08
P14: X2; Pin_Header_Straight_1x08
P16: D1; Pin_Header_Straight_1x03
R1, R2, R3: 10k; R_1206_HandSoldering
U1, U2, U3, U4, U5, U6: 74LVC8T245; TSSOP24-44

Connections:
+3V3: C1.1, C3.1, C5.1, C7.1, C9.1, C11.1, P8.2, U1.23 (VccB), U1.24 (VccB), U2.23 (VccB), U2.24 (VccB), U3.23 (VccB), U3.24 (VccB), U4.23 (VccB), U4.24 (VccB), U5.23 (VccB), U5.24 (VccB), U6.23 (VccB), U6.24 (VccB)
+5V: C2.1, C4.1, C6.1, C8.1, C10.1, C12.1, CON-Z21.5 (+5V), CON-Z21.6 (+5V), R1.2, R2.2, R3.2, U1.1 (VccA), U1.2 (DIR), U2.1 (VccA), U2.2 (DIR), U3.1 (VccA), U3.2 (DIR), U4.1 (VccA), U5.1 (VccA), U5.2 (DIR), U6.1 (VccA)
GND: C1.2, C2.2, C3.2, C4.2, C5.2, C6.2, C7.2, C8.2, C9.2, C10.2, C11.2, C12.2, CON-Z21.1 (GND), CON-Z21.2 (GND), CON-Z21.3 (GND), CON-Z21.4 (GND), CON-Z21.13 (GND), CON-Z21.25 (GND), CON-Z21.37 (GND), CON-Z21.49 (GND), CON-Z21.61 (GND), CON-Z21.73 (GND), CON-Z21.85 (GND), CON-Z21.87 (GND), CON-Z21.88 (GND), CON-Z21.89 (GND), CON-Z21.90 (GND), CON-Z21.99 (GND), CON-Z21.100 (GND), P8.1, U1.11 (GND), U1.12 (GND), U1.13 (GND), U1.22 (/OE), U2.11 (GND), U2.12 (GND), U2.13 (GND), U2.22 (/OE), U3.11 (GND), U3.12 (GND), U3.13 (GND), U3.22 (/OE), U4.11 (GND), U4.12 (GND), U4.13 (GND), U4.22 (/OE), U5.11 (GND), U5.12 (GND), U5.13 (GND), U5.22 (/OE), U6.11 (GND), U6.12 (GND), U6.13 (GND), U6.22 (/OE)
unnamed: CON-Z21.9 (/SLAVEn), P16.2, R2.1
unnamed: CON-Z21.11 (/CFGOUTn), P16.1, R1.1
unnamed: CON-Z21.12 (/CFGINn), U2.3 (A1)
unnamed: CON-Z21.21 (A5), U1.10 (A8)
unnamed: CON-Z21.23 (A6), U1.9 (A7)
unnamed: CON-Z21.24 (A4), U5.10 (A8)
unnamed: CON-Z21.26 (A3), U5.9 (A7)
unnamed: CON-Z21.27 (A2), U1.8 (A6)
unnamed: CON-Z21.28 (A7), U5.8 (A6)
unnamed: CON-Z21.29 (A1), U1.7 (A5)
unnamed: CON-Z21.30 (A8), U5.7 (A5)
unnamed: CON-Z21.32 (A9), U5.6 (A4)
unnamed: CON-Z21.34 (A10), U5.5 (A3)
unnamed: CON-Z21.36 (A11), U5.4 (A2)
unnamed: CON-Z21.38 (A12), U5.3 (A1)
unnamed: CON-Z21.39 (A13), U1.6 (A4)
unnamed: CON-Z21.41 (A14), U1.5 (A3)
unnamed: CON-Z21.43 (A15), U1.4 (A2)
unnamed: CON-Z21.45 (A16), U1.3 (A1)
unnamed: CON-Z21.46 (/BERR), U2.4 (A2)
unnamed: CON-Z21.47 (A17), U2.10 (A8)
unnamed: CON-Z21.52 (A18), U3.10 (A8)
unnamed: CON-Z21.53 (/RST), U2.5 (A3)
unnamed: CON-Z21.54 (A19), U3.9 (A7)
unnamed: CON-Z21.56 (A20), U3.8 (A6)
unnamed: CON-Z21.57 (A22), U2.9 (A7)
unnamed: CON-Z21.58 (A21), U3.7 (A5)
unnamed: CON-Z21.59 (A23), U2.8 (A6)
unnamed: CON-Z21.63 (D15), U6.10 (A8)
unnamed: CON-Z21.65 (D14), U6.9 (A7)
unnamed: CON-Z21.67 (D13), U6.8 (A6)
unnamed: CON-Z21.68 (READ), U3.6 (A4)
unnamed: CON-Z21.69 (D12), U6.7 (A5)
unnamed: CON-Z21.70 (/LDS), U3.5 (A3)
unnamed: CON-Z21.71 (D11), U6.6 (A4)
unnamed: CON-Z21.72 (/UDS), U3.4 (A2)
unnamed: CON-Z21.74 (/CCS_/AS), U3.3 (A1)
unnamed: CON-Z21.75 (D0), U6.5 (A3)
unnamed: CON-Z21.76 (D10), U4.10 (A8)
unnamed: CON-Z21.77 (D1), U6.4 (A2)
unnamed: CON-Z21.78 (D9), U4.9 (A7)
unnamed: CON-Z21.79 (D2), U6.3 (A1)
unnamed: CON-Z21.80 (D8), U4.8 (A6)
unnamed: CON-Z21.81 (D3), U4.4 (A2)
unnamed: CON-Z21.82 (D7), U4.7 (A5)
unnamed: CON-Z21.83 (D4), U4.3 (A1)
unnamed: CON-Z21.84 (D6), U4.6 (A4)
unnamed: CON-Z21.86 (D5), U4.5 (A3)
unnamed: CON-Z21.92 (E7M), U2.6 (A4)
unnamed: CON-Z21.93 (DOE), U2.7 (A5)
unnamed: P1.2, U1.20 (B2)
unnamed: P1.3, U1.19 (B3)
unnamed: P1.4, U1.18 (B4)
unnamed: P1.6, U1.16 (B6)
unnamed: P1.7, U1.15 (B7)
unnamed: P1.8, U1.14 (B8)
unnamed: P2.2, U2.20 (B2)
unnamed: P2.3, U2.19 (B3)
unnamed: P2.4, U2.18 (B4)
unnamed: P2.6, U2.16 (B6)
unnamed: P2.7, U2.15 (B7)
unnamed: P2.8, U2.14 (B8)
unnamed: P3.2, U3.20 (B2)
unnamed: P3.3, U3.19 (B3)
unnamed: P3.4, U3.18 (B4)
unnamed: P3.6, U3.16 (B6)
unnamed: P3.7, U3.15 (B7)
unnamed: P3.8, U3.14 (B8)
unnamed: P4.1, U4.20 (B2)
unnamed: P4.2, U4.19 (B3)
unnamed: P4.3, U4.18 (B4)
unnamed: P4.5, U4.16 (B6)
unnamed: P4.6, U4.15 (B7)
unnamed: P4.7, U4.14 (B8)
unnamed: P5.2, U5.20 (B2)
unnamed: P5.3, U5.19 (B3)
unnamed: P5.4, U5.18 (B4)
unnamed: P5.6, U5.16 (B6)
unnamed: P5.7, U5.15 (B7)
unnamed: P5.8, U5.14 (B8)
unnamed: P6.1, U6.20 (B2)
unnamed: P6.2, U6.19 (B3)
unnamed: P6.3, U6.18 (B4)
unnamed: P6.5, U6.16 (B6)
unnamed: P6.6, U6.15 (B7)
unnamed: P6.7, U6.14 (B8)
unnamed: P13.1, U6.21 (B1)
unnamed: P13.2, U6.17 (B5)
unnamed: P13.3, U4.21 (B1)
unnamed: P13.5, U4.17 (B5)
unnamed: P13.6, U1.21 (B1)
unnamed: P13.7, U1.17 (B5)
unnamed: P14.1, U3.21 (B1)
unnamed: P14.2, U3.17 (B5)
unnamed: P14.3, U5.21 (B1)
unnamed: P14.5, U5.17 (B5)
unnamed: P14.6, U2.21 (B1)
unnamed: P14.7, U2.17 (B5)
unnamed: P16.3, R3.1, U4.2 (DIR), U6.2 (DIR)

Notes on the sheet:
Can you dig it?

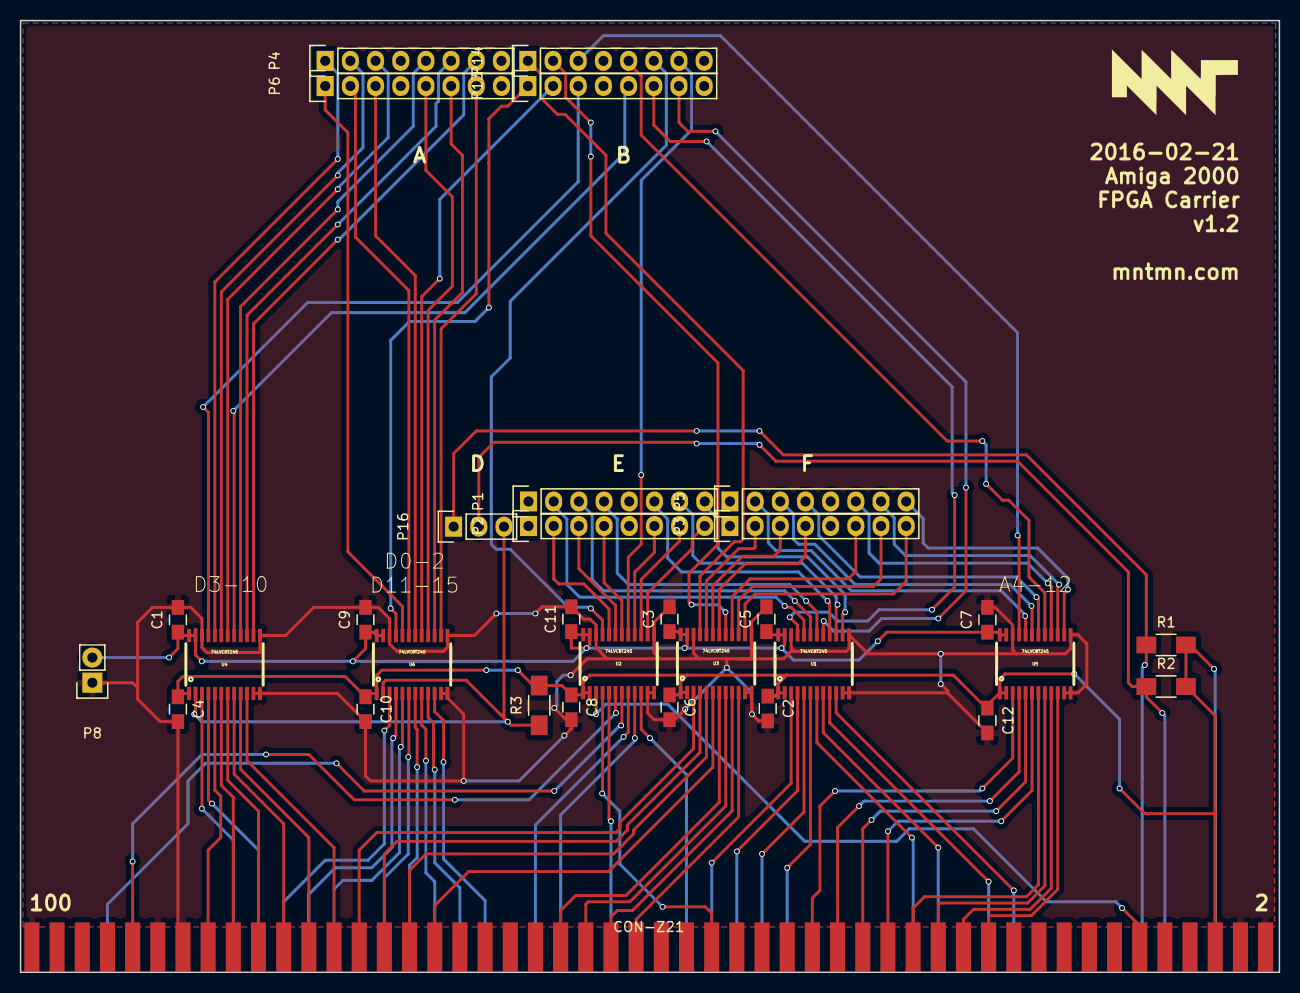
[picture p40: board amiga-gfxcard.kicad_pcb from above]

Board: 2 copper layers, 127.0 x 96.0 mm, 32 parts (0 on the bottom side), 102 nets.

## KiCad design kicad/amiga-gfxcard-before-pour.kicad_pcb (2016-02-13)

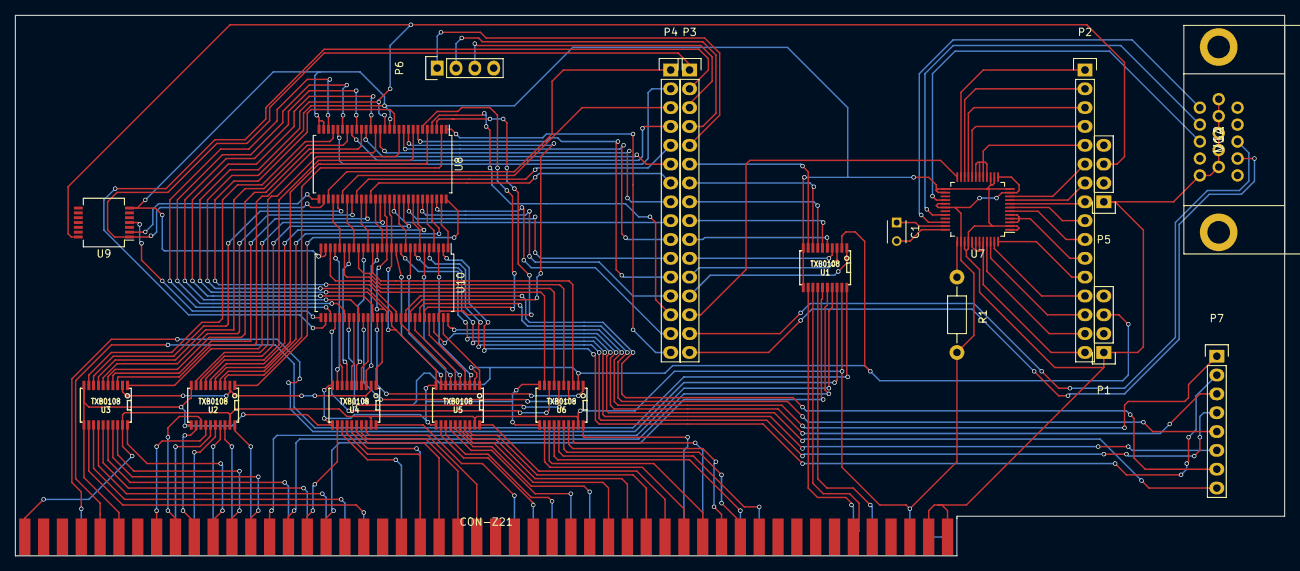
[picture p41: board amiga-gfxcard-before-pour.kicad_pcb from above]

Board: 2 copper layers, 171.2 x 72.9 mm, 21 parts (0 on the bottom side), 172 nets.

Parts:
C1: 0.1uF; C_Disc_D3_P2.5
CON-Z21: zorro2port; zorro2card
P1, P5, P6: CONN_01X04; Pin_Header_Straight_1x04
P2, P3, P4: CONN_01X16; Pin_Header_Straight_1x16
P7: CONN_01X08; Pin_Header_Straight_1x08
R1: 82k; Resistor_Horizontal_RM10mm
U1, U2, U3, U4, U5, U6: TXB0108; TSSOP20_PW
U7: ADV7125-lqfp48; LQFP-48_7x7mm_Pitch0.5mm
U8, U10: SN74CBT16233; SSOP-56_7.5x18.5mm_Pitch0.635mm
U9: 74LS04; SSOP-14_5.3x6.2mm_Pitch0.65mm
U12: VGA; HD15_B-HD15F

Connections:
//AS: CON-Z21.74, U1.17
//LDS: CON-Z21.70, U4.12
//UDS: CON-Z21.72, U1.16
/A1: CON-Z21.29, U6.20
/A8: CON-Z21.30, U6.12
/A9: CON-Z21.32, U5.20
/A16: CON-Z21.45, U5.12
/A17: CON-Z21.47, U4.20
/A23: CON-Z21.59, U4.13
/D0: CON-Z21.75, U2.20
/D7: CON-Z21.82, U2.12
/D8: CON-Z21.80, U3.20
/D15: CON-Z21.63, U3.12
GND: CON-Z21.1, CON-Z21.2, CON-Z21.3, CON-Z21.4, CON-Z21.90, P1.1, P5.1, U1.10, U1.11, U2.10, U2.11, U3.10, U3.11, U4.10, U4.11, U5.10, U5.11, U6.10, U6.11, U7.1, U7.2, U7.12, U7.14, U7.15, U7.25, U7.26, U7.39, U7.40, U8.13, U8.27, U8.28, U8.44, U9.7, U10.13, U10.27, U10.28, U10.44, U12.5, U12.6, U12.7, U12.8, U12.9, U12.10
unnamed: C1.1, U7.35
unnamed: C1.2, U7.36
unnamed: CON-Z21.9, U1.14
unnamed: CON-Z21.11, U1.12
unnamed: CON-Z21.12, U1.13
unnamed: CON-Z21.21, U6.15
unnamed: CON-Z21.23, U6.14
unnamed: CON-Z21.24, U6.16
unnamed: CON-Z21.26, U6.17
unnamed: CON-Z21.27, U6.18
unnamed: CON-Z21.28, U6.13
unnamed: CON-Z21.34, U5.18
unnamed: CON-Z21.36, U5.17
unnamed: CON-Z21.38, U5.16
unnamed: CON-Z21.39, U5.15
unnamed: CON-Z21.41, U5.14
unnamed: CON-Z21.43, U5.13
unnamed: CON-Z21.52, U4.18
unnamed: CON-Z21.54, U4.17
unnamed: CON-Z21.56, U4.16
unnamed: CON-Z21.57, U4.15
unnamed: CON-Z21.58, U4.14
unnamed: CON-Z21.65, U3.13
unnamed: CON-Z21.67, U3.14
unnamed: CON-Z21.68, U1.15
unnamed: CON-Z21.69, U3.15
unnamed: CON-Z21.71, U3.16
unnamed: CON-Z21.76, U3.17
unnamed: CON-Z21.77, U2.18
unnamed: CON-Z21.78, U3.18
unnamed: CON-Z21.79, U2.17
unnamed: CON-Z21.81, U2.16
unnamed: CON-Z21.83, U2.15
unnamed: CON-Z21.84, U2.13
unnamed: CON-Z21.86, U2.14
unnamed: CON-Z21.92, U1.20
unnamed: CON-Z21.93, U1.18
unnamed: CON-Z21.5, CON-Z21.6, CON-Z21.100, R1.2, U1.19, U2.19, U3.19, U4.19, U5.19, U6.19, U7.11, U7.13, U7.29, U7.30, U7.38
unnamed: P1.3, U1.2, U2.2, U3.2, U4.2, U5.2, U6.2
unnamed: P2.1, U7.23
unnamed: P2.2, U7.22
unnamed: P2.3, U7.21
unnamed: P2.4, U7.20
unnamed: P2.5, U7.16, U7.17, U7.18, U7.19
unnamed: P2.6, U7.10
unnamed: P2.7, U7.9
unnamed: P2.8, U7.8
unnamed: P2.9, U7.7
unnamed: P2.10, U7.6
unnamed: P2.11, U7.3, U7.4, U7.5
unnamed: P2.12, U7.48
unnamed: P2.13, U7.47
unnamed: P2.14, U7.46
unnamed: P2.15, U7.45
unnamed: P2.16, U7.41, U7.42, U7.43, U7.44
unnamed: P3.1, U8.30, U9.1
unnamed: P3.2, U10.30
unnamed: P3.3, P6.3
unnamed: P3.4, P6.2
unnamed: P3.5, P6.1
unnamed: P3.6, U1.9
unnamed: P3.7, U1.8
unnamed: P3.8, U1.7
unnamed: P3.9, U1.6
unnamed: P3.10, U1.5
unnamed: P3.11, U1.4
unnamed: P3.12, U1.3
unnamed: P3.13, U1.1
unnamed: P3.14, U7.24
unnamed: P3.15, U12.13
unnamed: P3.16, U12.14
unnamed: P4.1, U8.31
unnamed: P4.2, U8.24
unnamed: P4.3, U8.34
unnamed: P4.4, U8.21
unnamed: P4.5, U8.37
unnamed: P4.6, U8.18
unnamed: P4.7, U8.40
unnamed: P4.8, U8.15
unnamed: P4.9, U8.45
unnamed: P4.10, U8.10
unnamed: P4.11, U8.48
unnamed: P4.12, U8.7
unnamed: P4.13, U8.51
unnamed: P4.14, U8.4
unnamed: P4.15, U8.54
unnamed: P4.16, U8.1
unnamed: P5.3, U8.14, U8.43, U10.14, U10.43
unnamed: P7.1, U10.56
unnamed: P7.2, U10.2
unnamed: P7.3, U10.53
unnamed: P7.4, U10.5
unnamed: P7.5, U10.50
unnamed: P7.6, U10.8
unnamed: P7.7, U10.47
unnamed: P7.8, U10.11
unnamed: R1.1, U7.37
unnamed: U2.1, U8.56
unnamed: U2.3, U8.2
unnamed: U2.4, U8.53
unnamed: U2.5, U8.5
unnamed: U2.6, U8.50
unnamed: U2.7, U8.8
unnamed: U2.8, U8.47
unnamed: U2.9, U8.11
unnamed: U3.1, U8.42
unnamed: U3.3, U8.16
unnamed: U3.4, U8.39
unnamed: U3.5, U8.19
unnamed: U3.6, U8.36
unnamed: U3.7, U8.22
unnamed: U3.8, U8.33
unnamed: U3.9, U8.25
unnamed: U8.29, U9.2
unnamed: U8.55, U10.1
unnamed: U5.3, U10.3
unnamed: U8.52, U10.4
unnamed: U5.5, U10.6
unnamed: U8.49, U10.7
unnamed: U5.7, U10.9
unnamed: U8.46, U10.10
unnamed: U5.9, U10.12
unnamed: U8.41, U10.15
unnamed: U4.3, U10.16
unnamed: U6.3, U10.17
unnamed: U8.38, U10.18
unnamed: U4.5, U10.19
unnamed: U6.5, U10.20
unnamed: U8.35, U10.21
unnamed: U4.7, U10.22
unnamed: U6.7, U10.23
unnamed: U8.32, U10.24
unnamed: U4.9, U10.25
unnamed: U6.9, U10.26
unnamed: U9.4, U10.29
unnamed: U8.26, U10.31
unnamed: U6.8, U10.32
unnamed: U4.8, U10.33
unnamed: U8.23, U10.34
unnamed: U6.6, U10.35
unnamed: U4.6, U10.36
unnamed: U8.20, U10.37
unnamed: U6.4, U10.38
unnamed: U4.4, U10.39
unnamed: U8.17, U10.40
unnamed: U6.1, U10.41
unnamed: U4.1, U10.42
unnamed: U8.12, U10.45
unnamed: U5.8, U10.46
unnamed: U8.9, U10.48
unnamed: U5.6, U10.49
unnamed: U8.6, U10.51
unnamed: U5.4, U10.52
unnamed: U8.3, U10.54
unnamed: U5.1, U10.55
unnamed: U7.34, U12.1
unnamed: U7.32, U12.2
unnamed: U7.28, U12.3

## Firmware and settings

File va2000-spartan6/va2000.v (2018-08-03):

`timescale 1ns / 1ns
// Company: MNT Media and Technology UG
// Engineer: Lukas F. Hartmann (@mntmn)
// Create Date:    21:49:19 03/22/2016 
// Design Name:    Amiga 2000/3000/4000 Graphics Card (VA2000) Revision 1.9.0 (2018-07-14)
// Module Name:    va2000
// Target Devices: 

module va2000(
input CLK50,

// zorro
input znCFGIN,
output znCFGOUT,
output znSLAVEN,
output zXRDY,
input znBERR,
input znRST,
input zE7M,
input zREAD,
input zDOE,

// z3
input zSENSEZ3,
input znFCS,
input zFC0,
input zFC1,
input zFC2,
input znDS0,
input znDS1,
output znCINH,
output znDTACK,

// address bus
input znAS,
input znUDS, // ds2+ds3
input znLDS,
inout [22:0] zA,

// data bus
output zDIR1,
output zDIR2,
output zDIR3,
output zDIR4,
inout [15:0] zD,

// SD
output SD_nCS,
output SD_MOSI,
input  SD_MISO,
output SD_SCLK,
input SD_DAT1,
input SD_DAT2,

// Capture
input videoHS,
input videoVS,
input videoR0,
input videoR1,
input videoR2,
input videoR3,
input videoG0,
input videoG1,
input videoG2,
input videoG3,
input videoB0,
input videoB1,
input videoB2,
input videoB3,

// SDRAM
output SDRAM_CLK,  
output SDRAM_CKE,  
output SDRAM_nCS,   
output SDRAM_nRAS,  
output SDRAM_nCAS,
output SDRAM_nWE,   
output [1:0]  SDRAM_DQM,  
output [12:0] A, 
output [1:0]  SDRAM_BA,
inout  [15:0] D,

// HDMI
output [3:0] TMDS_out_P,
output [3:0] TMDS_out_N

`ifdef SIMULATION
,
input z_sample_clk,
input vga_clk,
input dcm7_0,
input dcm7_180,
output [7:0] vga_r,
output [7:0] vga_g,
output [7:0] vga_b,
output vga_hs,
output vga_vs
`endif
);

reg clk_reset=0;
reg [1:0] vga_clk_sel = 0;
reg [1:0] vga_clk_sel0_latch = 0;

//`define ZORRO2
`define ZORRO3
//`define PIXCLK_100

`ifndef SIMULATION
// pixel clock selector
// 00 == 75mhz or 100mhz
// 01 == 40mhz
// #(.CLK_SEL_TYPE("ASYNC"))

BUFGMUX vga_clk_mux2(
  .O(vga_clk),
  .I0(clk75_unbuffered),
  .I1(clk40_unbuffered),
  .S(vga_clk_sel0_latch[1])
);
`endif

// sd card interface
reg sd_reset = 0;
reg sd_read = 0;
reg sd_write = 0;
reg sd_continue = 0;

reg [31:0] sd_addr_in = 0;
reg [7:0] sd_data_in = 0;
reg sd_handshake_in = 0;

wire sd_busy;
wire [7:0] sd_data_out;
wire [15:0] sd_error;
wire sd_handshake_out;
wire sd_state;

reg [7:0] sd_data_out_sync;
reg [15:0] sd_error_sync;
reg sd_busy_sync;
reg sd_handshake_out_sync;

`ifndef SIMULATION
SdCardCtrl sdcard(
  .clk_i(sd_clk),
  .reset_i(sd_reset),
  .rd_i(sd_read),
  .wr_i(sd_write),
  .continue_i(sd_continue),
  .addr_i(sd_addr_in),
  .data_i(sd_data_in),
  .data_o(sd_data_out),
  .busy_o(sd_busy),
  .error_o(sd_error),
  .state_o(sd_state),
  
  .cs_bo(SD_nCS),
  .mosi_o(SD_MOSI),
  .miso_i(SD_MISO),
  .sclk_o(SD_SCLK),
  
  .hndShk_i(sd_handshake_in),
  .hndShk_o(sd_handshake_out)
);
`endif

reg  sdram_reset = 0;
reg  ram_enable = 0;
reg  [23:0] ram_addr = 0;
wire [15:0] ram_data_out;
wire data_out_ready;
wire data_out_queue_empty;
wire [4:0] sdram_state;
wire sdram_btb;
reg  [15:0] ram_data_in;
reg  [15:0] ram_data_in_next;
reg  ram_write = 0;
reg  [2:0] ram_burst_size = 0;
reg  [1:0]  ram_byte_enable;

parameter FETCHW = 512;
reg  [15:0] fetch_buffer [0:(FETCHW+8)];
reg  [23:0] scale_buffer [0:639];
reg  [15:0] sb0;
reg signed [11:0] fetch_x = 0;

reg  [23:0] fetch_y = 0;
reg  [31:0] pan_ptr = 0;
reg  [31:0] pan_ptr_sync = 0;
reg  fetching = 0;

reg display_enable = 1;

reg [11:0] fetch_w = FETCHW;
reg [15:0] fetch_preroll = 0;

reg [15:0] row_pitch = 1024;

reg [15:0] blitter_row_pitch = 2048;

// custom refresh mechanism
reg [23:0] refresh_addr = 0;
reg [23:0] refresh_counter = 0;
reg [23:0] refresh_max = 'h100;
reg [23:0] refresh_saved_addr = 0;

reg [4:0] refresh_warm_counter = 0;
reg [4:0] refresh_warm_max = 10;
reg [4:0] refresh_cool_counter = 0;
reg [4:0] refresh_cool_max = 10;
reg [4:0] ram_fetch_delay_counter = 0;
reg [4:0] ram_fetch_delay_max = 0;
reg [4:0] ram_fetch_delay2_counter = 0;
reg [4:0] ram_fetch_delay2_max = 0;

// SDRAM
SDRAM_Controller_v sdram(
  .clk(z_sample_clk),
  .reset(sdram_reset),
  .idle(sdram_idle),
  
  // command and write port
  .cmd_ready(cmd_ready),
  .cmd_enable(ram_enable),
  .cmd_wr(ram_write),
  .cmd_byte_enable(ram_byte_enable),
  .cmd_address(ram_addr),
  .cmd_data_in(ram_data_in),
  .cmd_data_in_next(ram_data_in_next),
  .burst_size(ram_burst_size),
  
  // read data port
  .data_out(ram_data_out),
  .data_out_ready(data_out_ready),
  .data_out_queue_empty(data_out_queue_empty),

  // signals
  .SDRAM_CLK(SDRAM_CLK),
  .SDRAM_CKE(SDRAM_CKE),
  .SDRAM_CS(SDRAM_nCS),
  .SDRAM_RAS(SDRAM_nRAS),
  .SDRAM_CAS(SDRAM_nCAS),
  .SDRAM_WE(SDRAM_nWE),
  .SDRAM_DATA(D),
  .SDRAM_ADDR(A),
  .SDRAM_DQM(SDRAM_DQM),
  .SDRAM_BA(SDRAM_BA)
);

// dvi out
reg [7:0] red_p;
reg [7:0] green_p;
reg [7:0] blue_p;
reg [7:0] red_p_dly;
reg [7:0] green_p_dly;
reg [7:0] blue_p_dly;
reg dvi_vsync;
reg dvi_hsync;
reg dvi_blank;
reg dvi_vsync_dly;
reg dvi_hsync_dly;
reg dvi_blank_dly;
reg [3:0] tmds_out_pbuf;
reg [3:0] tmds_out_nbuf;
assign TMDS_out_P = tmds_out_pbuf;
assign TMDS_out_N = tmds_out_nbuf;
reg dvid_reset = 1;
reg [1:0] dvid_reset_sync = 1;
reg dvi_vsync_reg;

`ifdef SIMULATION
  assign vga_r = red_p;
  assign vga_g = green_p;
  assign vga_b = blue_p;
  assign vga_hs = dvi_hsync;
  assign vga_vs = dvi_vsync;
`endif

`ifndef SIMULATION
dvid_out dvid_out(
  // Clocking
  .clk_pixel(vga_clk),
  // VGA signals
  .red_p(red_p),
  .green_p(green_p),
  .blue_p(blue_p),
  .blank(dvi_blank),
  .hsync(dvi_hsync),
  .vsync(dvi_vsync),
  // TMDS outputs
  .tmds_out_p(tmds_out_pbuf),
  .tmds_out_n(tmds_out_nbuf),
  .reset(dvid_reset_sync[1])
);
`endif

// vga registers -------------------------------------------------------------
reg [11:0] counter_x = 0;
reg [11:0] counter_y = 0;
reg [11:0] display_x2 = 0;
reg [11:0] display_x3 = 0;

// modeline -------------------------------------------------------------
reg [11:0] h_rez        = 1280;
reg [11:0] h_sync_start = 1280+72;
reg [11:0] h_sync_end   = 1280+80;
reg [11:0] h_max        = 1647;
reg [11:0] v_rez        = 720;
reg [11:0] v_sync_start = 720+3;
reg [11:0] v_sync_end   = 720+8;
reg [11:0] v_max        = 749;
reg [11:0] screen_w = 1280;
reg [11:0] screen_h = 720;
reg [11:0] screen_w_sync = 1280;

// zorro port buffers / flags -------------------------------------------------------------
reg ZORRO3 = 1; 
reg [23:0] zaddr; // zorro 2 address
reg [23:0] zaddr_sync;
reg [23:0] zaddr_sync2;
reg [23:0] zaddr_sync3;
reg [23:0] z2_mapped_addr;
reg [15:0] data;
reg [15:0] data_in;
reg [15:0] regdata_in;
reg [15:0] data_z3_hi16;
reg [15:0] data_z3_low16;

reg [15:0] data_z3_hi16_latched;
reg [15:0] data_z3_low16_latched;

reg [15:0] data_in_z3_low16;
reg [15:0] zdata_in_sync;
reg [15:0] z3_din_high_s2;
reg [15:0] z3_din_low_s2;
reg [31:0] z3addr;
reg [31:0] z3addr2;
reg [31:0] z3addr3;
reg [31:0] z3_mapped_addr;
reg [31:0] z3_read_addr;
reg [15:0] z3_read_data;
reg [31:0] rr_data;

reg z_confout = 0;
assign znCFGOUT = znCFGIN?1'b1:(~z_confout);
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

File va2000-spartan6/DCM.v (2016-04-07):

// $Header: /devl/xcs/repo/env/Databases/CAEInterfaces/verunilibs/data/unisims/DCM.v,v 1.36 2008/07/11 20:26:52 yanx Exp $
///////////////////////////////////////////////////////////////////////////////
// Copyright (c) 1995/2004 Xilinx, Inc.
// All Right Reserved.
///////////////////////////////////////////////////////////////////////////////
//   ____  ____
//  /   /\/   /
// /___/  \  /    Vendor : Xilinx
// \   \   \/     Version : 10.1
//  \   \         Description : Xilinx Function Simulation Library Component
//  /   /                  Digital Clock Manager
// /___/   /\     Filename : DCM.v
// \   \  /  \    Timestamp : Thu Mar 25 16:43:54 PST 2004
//  \___\/\___\
//
// Revision:
//    03/23/04 - Initial version.
//    03/11/05 - Add LOC parameter.
//    04/11/05 - Initial all output signals..
//    05/06/05 - Use assign/deassign to reset all output clocks. CR 207692.
//    05/11/05 - Add clkin alignment check control to remove the glitch when
//               clkin stopped. (CR207409).
//    05/25/05 - Seperate clock_second_pos and neg to another process due to
//               wait caused unreset. Set fb_delay_found after fb_delay computed.
//               Enable clkfb_div after lock_fb high (CR 208771)
//    07/05/05 - Use counter to generate clkdv_out to align with clk0_out. (CR211465).
//               Add lock_fb_dly to alignment check. (CR210755).
//    07/25/05 - Set CLKIN_PERIOD default to 10.0ns to (CR 213190)
//    12/22/05 - LOCKED = x when RST less than 3 clock cycles (CR 222795)
//    01/12/06 - Add rst_in to period_div and period_ps block to handle clkin frequency 
//               change case. (CR 221989).
//    02/28/06 - Add integer and real to parameter declaration.
//    09/22/06 - Add lock_period and lock_fb to clkfb_div block (CR418722).
//    12/19/06 - Add clkfb_div_en for clkfb2x divider (CR431210).
//    04/06/07 - Enable the clock out in clock low time after reset in model
//               clock_divide_by_2  (CR 437471).
//    06/04/07 - Add parameter SIM_MODE (SLIB_M2.1)
//    02/21/08 - Align clk2x to both clk0 pos and neg edges (CR467858).
//    03/01/08 - Disable alignment of clkfb and clkin_fb check when ps_lock high (CR468893).
//    07/08/08 - Use clkin_div instead of period to generate lock_period_dly (CR476425)
// End Revision


`timescale  1 ps / 1 ps

module DCM (
	CLK0, CLK180, CLK270, CLK2X, CLK2X180, CLK90,
	CLKDV, CLKFX, CLKFX180, LOCKED, PSDONE, STATUS,
	CLKFB, CLKIN, DSSEN, PSCLK, PSEN, PSINCDEC, RST);

parameter real CLKDV_DIVIDE = 2.0;
parameter integer CLKFX_DIVIDE = 1;
parameter integer CLKFX_MULTIPLY = 4;
parameter CLKIN_DIVIDE_BY_2 = "FALSE";
parameter real CLKIN_PERIOD = 10.0;			// non-simulatable
parameter CLKOUT_PHASE_SHIFT = "NONE";
parameter CLK_FEEDBACK = "1X";
parameter DESKEW_ADJUST = "SYSTEM_SYNCHRONOUS";	// non-simulatable
parameter DFS_FREQUENCY_MODE = "LOW";
parameter DLL_FREQUENCY_MODE = "LOW";
parameter DSS_MODE = "NONE";			// non-simulatable
parameter DUTY_CYCLE_CORRECTION = "TRUE";
parameter FACTORY_JF = 16'hC080;		// non-simulatable
localparam integer MAXPERCLKIN = 1000000;		// non-modifiable simulation parameter
localparam integer MAXPERPSCLK = 100000000;		// non-modifiable simulation parameter
parameter integer PHASE_SHIFT = 0;
localparam integer SIM_CLKIN_CYCLE_JITTER = 300;		// non-modifiable simulation parameter
localparam integer SIM_CLKIN_PERIOD_JITTER = 1000;	// non-modifiable simulation parameter
parameter SIM_MODE = "SAFE";
parameter STARTUP_WAIT = "FALSE";		// non-simulatable


input CLKFB, CLKIN, DSSEN;
input PSCLK, PSEN, PSINCDEC, RST;

output CLK0, CLK180, CLK270, CLK2X, CLK2X180, CLK90;
output CLKDV, CLKFX, CLKFX180, LOCKED, PSDONE;
output [7:0] STATUS;

reg CLK0=0, CLK180=0, CLK270=0, CLK2X=0, CLK2X180=0, CLK90=0;
reg CLKDV=0, CLKFX=0, CLKFX180=0;

wire clkfx_lost_out, clkin_lost_out;
wire locked_out_out;
wire clkfb_in, clkin_in, dssen_in;
wire psclk_in, psen_in, psincdec_in, rst_in;
reg clk0_out;
reg clk2x_out, clkdv_out;
reg clkfx_out, clkfx180_en;
reg rst_flag;
reg locked_out, psdone_out, ps_overflow_out, ps_lock;
reg clkfb_div, clkfb_chk, clkfb_div_en;
integer clkdv_cnt;

reg [1:0] clkfb_type;
reg [8:0] divide_type;
reg clkin_type;
reg [1:0] ps_type;
reg [3:0] deskew_adjust_mode;
reg dfs_mode_type;
reg dll_mode_type;
reg clk1x_type;
integer ps_in, ps_in_ps;

reg lock_period, lock_delay, lock_clkin, lock_clkfb;
reg first_time_locked;
reg en_status;
reg ps_overflow_out_ext = 0;
reg clkin_lost_out_ext = 0;
reg clkfx_lost_out_ext = 0;
reg [1:0] lock_out;
reg lock_out1_neg;
reg lock_fb, lock_ps, lock_ps_dly, lock_fb_dly, lock_fb_dly_tmp;
reg fb_delay_found;
reg clock_stopped;
reg clkin_chkin, clkfb_chkin;

wire chk_enable, chk_rst;
wire clkin_div;
wire lock_period_pulse;
reg lock_period_dly;

reg clkin_ps;
reg clkin_fb;

time FINE_SHIFT_RANGE;
time ps_delay;
time clkin_edge;
time clkin_div_edge;
time clkin_ps_edge;
time delay_edge;
time clkin_period [2:0];
time period;
time period_div;
time period_orig;
time period_ps;
time clkout_delay;
time fb_delay;
time period_fx, remain_fx;
time period_dv_high, period_dv_low;
time cycle_jitter, period_jitter;

reg clkin_window, clkfb_window;
reg [2:0] rst_reg;
reg [12:0] numerator, denominator, gcd;
reg [23:0] i, n, d, p;

reg notifier;

   reg LOCKED_out ;

   reg        align, clkin_divide, fbsync = 0;
   reg [2:0] pos_shift, neg_shift;
   reg [2:0] pos_shift_st, neg_shift_st;
   reg [1:0] clkin_cnt, old_clkin_cnt;
   reg       clkin_error;
   reg       period_updated;
   reg       clkin_cnt_en;
   reg       rst_tmp, rst_done_fx, rst_done_dv;
   integer   shift;

   realtime  clk_period; // = (250*CLKIN_PERIOD);
   realtime  clkfx_period; // = ((CLKIN_PERIOD*CLKFX_DIVIDE*1000)/(CLKFX_MULTIPLY*2));
   realtime  shift_ammount; // = ((CLKIN_PERIOD*1000)/256);
   realtime  clkdv_period; // = ((CLKIN_PERIOD*CLKDV_DIVIDE*1000)/2);
   realtime  clkin_time1, clkin_time2, period_clkin;

   time      start_time, delay_time;
   integer t;
   
initial begin
    #1;
    if ($realtime == 0) begin
	$display ("Simulator Resolution Error : Simulator resolution is set to a value greater than 1 ps.");
	$display ("In order to simulate the DCM, the simulator resolution must be set to 1ps or smaller.");
	$finish;
    end
end
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

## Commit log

2016-02-17 WIP of simpler redesign for miniSpartan 6+
    [amiga-gfxcard-old.kicad_pcb, amiga-gfxcard.kicad_pcb, amiga-gfxcard.sch]
2016-02-18 WIP new PCB
    [amiga-gfxcard.kicad_pcb]
2016-02-18 redo of mk2 board finished
    [amiga-gfxcard.kicad_pcb, amiga-gfxcard.sch]
2016-02-21 board v1.2 finished
    [amiga-gfxcard.kicad_pcb, amiga-gfxcard.sch]
2016-03-27 Version 2, new board, minispartan 6+, working DVI/HDMI output
    [amiga-gfxcard-B_Cu.gbr, amiga-gfxcard-B_Mask.gbr, amiga-gfxcard-B_Paste.gbr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]
2016-04-09 quite stable writes; fix weird 16bit 'pc' color interpretation
    [z2.v]
2016-04-24 disable sdram refresh; less glitches
    [z2.v]
2016-04-24 read-to-fetch timer test
2016-05-05 xrdy mechanism; display stable; minimal wrong pixels
    [z2.v]
2016-05-06 optimal de-glitching parameters
2016-05-14 working autoconfig(tm), experimental video slot grabber, experimental sd/spi interface
2016-05-15 first partly working version of SD card driver
2016-05-21 WIP clean-room card driver headers compatible with a popular RTG library
2016-05-22 rtg driver WIP
2016-05-24 debug uart; fix read/write addr noise
    [z2.v]
2016-05-25 stable read/writes, no more ffff noise; added missing uart source
    [z2.v]
2016-05-26 first working gfx driver
2016-05-28 WIP with blitter and working C gfx driver
2016-06-19 first working SD card driver; minimized flickering when blitter is copying
2016-06-28 stability tweaks to SD card device
    [mntsd_device.c]
2016-07-10 fix gfx driver board flags
2016-08-29 copy timing and scaling problems solved
    [z2.v]
2016-10-30 SD_BASE for sd card driver
2016-11-28 fix blitter driver for renderinfo offsets etc
2016-12-11 beta release WIP. 32bit, fix some timing problems, introduce custom refresh, fix sd card drivers, sd card CRC, custom resolutions, fix z3 register read model
    [mntsd_device.c]
2016-12-13 fix SD card driver; much better timing
    [z2.v]
2016-12-14 a2000 tweaks (fixed read turd bug), working refresh
    [z2.v]
2016-12-22 fix corrupted Picasso96Settings file; init refresh timer in driver
2017-01-02 WIP cfgin/cfgout sequencing; fix possible deadlock when switching resolutions; some blitter optimization; revision number
    [z2.v]
2017-01-05 firmware 1.3rc1; fixes lockups and write errors switching between pixel clocks
    [z2.v]
2017-01-14 switch from xrdy to ovr/dtack mechanism; fix last glitches with default_data = ffff
    [z2.v]
2017-01-29 stable point after lots of 3000/030 z3 debugging. adds DOE gate, fixes some write/read race conditions
    [z2.v]
2017-02-08 added schematics of release board
2017-02-12 introduce 2-word burst in ram controller; accidentally fix long-standing bug; stable hi-res capture
    [z2.v]
2017-02-22 gfx driver cleanup & refactoring
2017-02-22 separate blitter pitch + colormode
2017-03-04 release 1.4; sync all vga signals across clocks; refactor some blitter code into more states; clear memory on reset; no more blue screen; sync some sd out signals; no more clock switching crashes
    [z2.v]
2017-03-05 videoslot expansion protoype
    [videoslot.kicad_pcb, videoslot.sch]
2017-03-12 VA2000CX corrections for PCB batch 1
    [videoslot.kicad_pcb, videoslot.sch]
2017-05-25 WIP 1.5b firmware, gfx drivers; mntmode, va2000cx initial commits
    [videoslot.kicad_pcb, videoslot.sch]
2017-07-24 1.6.1 firmware, drivers, va2000cx tool; mainly videocap improvements, new regs
2017-09-26 Release 1.7.2 FW, gfx & sd driver
2017-10-04 first OK prototype of linear framebuffer
2017-10-10 most modes and capture working correctly again
    [z2.v]
2017-10-10 register, blitter, refresh restructuring, 32bit scaler fixed
    [z2.v]
2017-10-11 1.8.2 beta 1 stable; slight pixel errors due to refresh
    [z2.v]
2017-10-11 beta1 drivers for 1.8.2, new framebuffer and blitter model
2017-10-26 firmware and gfx driver source for 1.8.3, updated va2000cx tool
2018-05-14 1.8.5 driver, missing .xise update
2018-07-18 working 32bit color mode and clean video grabber; only smaller glitches left
    [va2000.v]
2018-07-19 snapshot of glitch-free block copy
    [va2000.v]
2018-08-24 va2000cx: added duplicates of all needed symbols
    [videoslot.sch]
2019-03-25 cx r2 BOM
2019-03-25 Update of schematics and project files to KiCad 5.1
    [videoslot.sch]
2021-11-08 Update README.md
    https://forum.kicad.info/t/warning-avoid-all-links-to-kicad-pcb-org-use-kicad-org/31521
2021-11-08 Update README.html
    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
